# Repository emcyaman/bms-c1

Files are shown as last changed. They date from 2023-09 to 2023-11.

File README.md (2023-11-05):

# Libre Solar BMS C1

 Tested prototype, only minor issues left.

This repository contains the files for ongoing development of the Libre Solar BMS C1.

**Remark:** This BMS was previously named **BMS 16S100 SC**. It was renamed to C1 (with C for compact/centralized) because the maximum current and supported number of cells depend on the parts actually populated on the PCB, so these specs should not be encoded in the PCB name.

The development of this BMS is funded by the [EnAccess foundation](https://enaccess.org).

Schematic: [PDF file](build/bms-c1.pdf)

Bill of Materials: [CSV file](build/bms-c1_bom.csv) or [interactive HTML BOM](https://libre.solar/bms-c1/bms-c1_ibom.html)

Firmware repository: [LibreSolar/bms-firmware](https://github.com/LibreSolar/bms-firmware)

BMS C1

User manual: [libre.solar/bms-c1/manual/](https://libre.solar/bms-c1/manual/)

Mechanical CAD file: [bms-c1.FCStd](housing/bms-c1.FCStd)

Mechanical BOM: [bms-c1_bom_mechanical.csv](housing/bms-c1_bom_mechanical.csv)

Heat sink drawings: [10003_BackPlateAsm.pdf](housing/10003_BackPlateAsm.pdf)

Test report: [testing/v0.3](testing/v0.3/README.md)

## Features

- 3 to 16 Li-ion cells in series
- Continuous current: 70-100A (depending on used MOSFETs and heat sink)
- Cell types: LiFePO4, Li-ion NMC and others (customizable)
- Measurements
  - Cell voltages
  - Pack voltage
  - Pack current
  - Pack (2x), MOSFET and shunt temperatures
- Based on Texas Instruments bq76952
- Integrated high-side MOSFET switch and current sensor
- Espressif ESP32-C3 microcontroller
- Communication interfaces:
  - CAN
  - RS-485 (connector shared with CAN)
  - USB (CDC-ACM and JTAG)
  - USART
  - I2C
  - Bluetooth Low Energy
  - WiFi
- Hardware features
  - 4-layer PCB
  - M5 screw terminals
  - Heat sink at back side
- Applications
  - Off-grid storage
  - Light-electric vehicles (LEV)

## Firmware

The firmware is developed in a separate repository [LibreSolar/bms-firmware](https://github.com/LibreSolar/bms-firmware).

## License

The hardware is licensed under the [CERN Open Hardware Licence Version 2 - Weakly Reciprocal](LICENCE).

Documentation is licensed under the [Creative Commons Attribution-ShareAlike 4.0 International (CC BY-SA 4.0) License](https://creativecommons.org/licenses/by-sa/4.0/).

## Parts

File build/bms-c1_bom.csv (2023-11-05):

Component | References | Value | Footprint | Description | Quantity Per PCB | Manufacturer | PartNumber | Remarks
1 | C27 C29 C32 C33 C35 C38 | 100pF | C_0603_1608 | Unpolarized capacitor | 6 | any |  | 100V, C0G/NP0
2 | C19 C21 C24 C28 C31 C34 C36 C37 C40 C48 C49 C50 C51 C52 | 100nF | C_0603_1608 | Unpolarized capacitor | 14 | any |  | X7R, 100V
3 | C1 C2 C3 C4 C5 C6 C7 C8 C9 C10 C11 C12 C13 C14 C15 C16 C26 | 220nF | C_0603_1608 | Unpolarized capacitor | 17 | any
4 | C25 | 1µF | C_1206_3216 | Unpolarized capacitor | 1 | any |  | 100V, X7R
5 | C30 C47 | 1µF | C_0603_1608 | Unpolarized capacitor | 2 | any |  | 25V, X5R
6 | C46 | 10µF | C_0805_2012 | Unpolarized capacitor | 1 | Murata | GRM21BR61E106KA73L | 25V, X5R
7 | C20 | 2.2µF | C_0603_1608 | Unpolarized capacitor | 1 | any |  | X7R, 10V
8 | C22 C23 | 2.2µF | C_1210_3225 | Unpolarized capacitor | 2 | any |  | 100V, X7R
9 | C17 C18 | 47µF | C_1210_3225 | Unpolarized capacitor | 2 | Samsung | CL32B476MPJNNNE | 10V, X5R
10 | D14 D17 D21 D24 | 16V | D_SOD-123 | Zener diode | 4 | Diodes Incorporated | MMSZ5246B-7-F | Alternative: Vishay MMSZ5246B-HE3-08
11 | D11 | 3.6V | D_SOD-123 | Zener diode | 1 | onsemi | MMSZ4685T1G
12 | D19 | 5.1V | D_SOD-323 | Zener diode | 1 | Diodes Incorporated | BZT52C5V1S-7-F | Vishay BZX384C5V1
13 | D23 | 75V | D_SOD-123 | Zener diode | 1 | Diodes Incorporated | MMSZ5267BT1G
14 | D2 D5 D10 D15 D16 D20 | BAT46W | D_SOD-123 | Schottky diode | 6 | Diodes Incorporated | BAT46W-7-F | Alternative: MCC BAT46WHE3-TP
15 | D3 D4 | ESD5B5.0ST1G | D_SOD-523 | ESD protection diode, 5.0Vrwm, SOD-923 | 2 | onsemi | ESD5B5.0ST1G
16 | D22 | MURS360 | D_SMC | Diode | 1 | Diodes Incorporated | MURS360 | Alternative: Other MURS360
17 | D8 | PESD2CANFD | SOT-23 | Dual Line CAN Bus Protector, 24Vrwm | 1 | Nexperia | PESD2CANFD24V-TR | Alternative: onsemi ESDONCAN1LT
18 | D1 | PMEG10010ELRX | D_SOD-123F | Schottky diode | 1 | Nexperia | PMEG10010ELRX | Alternative: Nexperia PMEG10030ELPX
19 | D13 | PMEG10010ELRX | D_SOD-123F | Schottky diode | 1 | Nexperia | PMEG10010ELRX | Alternative: Nexperia PMEG10030ELPX
20 | D12 | SMCJ70A | D_SMC | Zener diode | 1 | Bourns | SMCJ70A | Alternative: Diodes Inc. SMCJ70A-13-F
21 | D9 | VSS8D3M10-M3/I | D_SOD-128 | Schottky diode | 1 | Vishay | VSS8D3M10-M3/I | Alternative: Nexperia PMEG10030ELPX
22 | J5 | B2B-PH-SM4 | JST_PH_B2B-PH-SM4-TB_1x02-1MP_P2.00mm_Vertical | Generic connectable mounting pin connector, single row, 01x02, script generated (kicad-library-utils/schlib/autogen/connector/) | 1 | JST | B2B-PH-SM4-TB(LF)(SN) | Alternative: Würth 620302124022
23 | J4 | B3B-PH-SM4 | JST_PH_B3B-PH-SM4-TB_1x03-1MP_P2.00mm_Vertical | Generic connectable mounting pin connector, single row, 01x03, script generated (kicad-library-utils/schlib/autogen/connector/) | 1 | JST | B3B-PH-SM4-TB(LF)(SN) | Alternative: Würth 620303124022
24 | J2 J6 | B4B-PH-SM4 | JST_PH_B4B-PH-SM4-TB_1x04-1MP_P2.00mm_Vertical | Generic connectable mounting pin connector, single row, 01x04, script generated (kicad-library-utils/schlib/autogen/connector/) | 2 | JST | B4B-PH-SM4-TB(LF)(SN) | Alternative: Würth 620304124022
25 | J1 | MicroFit 2x12 | Molex_Micro-Fit_3.0_43045-2410_2x12-1MP_P3.00mm_Horizontal | Generic connectable mounting pin connector, double row, 02x12, top/bottom pin numbering scheme (row 1: 1...pins_per_row, row2: pins_per_row+1 ... num_pins), script generated (kicad-library-utils/schlib/autogen/connector/) | 1 | Würth | 662024231722 | Mating connector: 662024113322
26 | J3 | USB_C_Receptacle_USB2.0 | USB_C_Receptacle_GCT_USB4105-xx-A_16P_TopMnt_Horizontal | USB 2.0-only Type-C Receptacle connector | 1 | GCT | USB4105-GF-A
27 | L2 | 22µH | Bourns_SRN8040TA | Inductor, small symbol | 1 | Tayo Yuden | NR8040T100M | Alternative: Bourns SRN8040TA-100M
28 | LED2 | LED green | LED_0603_1608Metric | Light emitting diode | 1 | any |  | green
29 | LED1 | LED red | LED_0603_1608Metric | Light emitting diode | 1 | any |  | red
30 | P1 P2 P3 P4 | CONN_01X01 | Wuerth_WP-SMBU_7466005R | Generic connector, single row, 01x01, script generated (kicad-library-utils/schlib/autogen/connector/) | 4 | Würth | 7466005R | Alternative: Erni 225858
31 | P5 | CONN_01X01 | SolderWirePad_1x01_SMD_5x10mm | Generic connector, single row, 01x01, script generated (kicad-library-utils/schlib/autogen/connector/) | 1
32 | Q11 | BSS123N | SOT-23 | N-MOSFET transistor, gate/source/drain | 1 | any | BSS123N
33 | Q10 | BSS84 | SOT-23 | P-MOSFET transistor, gate/source/drain | 1 | Nexperia | BSS84AK,215 | at least -20V
34 | Q1 | DMN10H220LE | SOT-223 | N-MOSFET transistor, gate/drain/source, drain connected to mounting plane | 1 | Diodes Inc. | DMN10H220LE | 100V, >2A, Alternative: IRFM120ATF
35 | Q2 Q3 Q4 Q5 Q6 Q7 Q8 Q9 | IPT015N10N5 | Infineon_PG-HSOF-8-1_ThermalVias | N-MOSFET transistor, gate/source/drain | 8 | Infineon | IPT015N10N5 | Alternative with 2mOhm: IPT020N10N3
36 | Q12 | ZXMP10A17GTA | SOT-223-3_TabPin2 | P-MOSFET transistor, gate/drain/source | 1 | Diodes Incorporated | ZXMP10A17GTA | Alternative: IRFL9110TRPBF
37 | R21 R37 | 0R | R_0603_1608 | Resistor | 2 | any
38 | R25 | 10 | R_1206_3216 | Resistor | 1 | any
39 | R1 R2 R3 R4 R5 R6 R7 R8 R9 R10 R11 R12 R13 R14 R15 R16 R17 | 20 | R_2010_5025 | Resistor | 17 | Yageo | RC2010JK-0720RL
40 | R63 | 40 | Bourns_PWR163 | Trim-potentiometer | 1 | Bourns | PWR163S-25-40R0FE
41 | R40 R41 R42 R43 R47 R48 R49 R50 R57 | 47 | R_0603_1608 | Resistor | 9 | any
42 | R34 | 52.3 | R_0603_1608 | Resistor | 1 | any |  | 1%
43 | R56 R64 | 62R | R_0603_1608 | Resistor | 2 | any
44 | R18 | 100 | R_1206_3216 | Resistor | 1 | any
45 | R19 R20 R38 R44 | 100 | R_0603_1608 | Resistor | 4 | any
46 | R45 | 300µ | R_Shunt_5931_Kelvin | Shunt resistor | 1 | Vishay | WSLP5931L3000FEA | Alternative: Bourns CSS2H-5930R-L300F
47 | R58 | 470 | R_0603_1608 | Resistor | 1 | any
48 | R22 R23 R46 | 1k | R_0603_1608 | Resistor | 3 | any
49 | R32 R33 | 2.2k | R_0603_1608 | Resistor | 2 | any
50 | R27 R35 R53 R54 | 5.1k | R_0603_1608 | Resistor | 4 | any
51 | R29 R30 R60 R68 | 10k | R_0603_1608 | Resistor | 4 | any
52 | R31 | 35.7k | R_0603_1608 | Resistor | 1 | any |  | 1%
53 | R51 R61 | 68k | R_0603_1608 | Resistor | 2 | any
54 | R28 R65 | 82k | R_0603_1608 | Resistor | 2 | any |  | 1%
55 | R24 R26 R62 | 1M | R_0603_1608 | Resistor | 3 | any
56 | R39 R52 R59 | 10M | R_0603_1608 | Resistor | 3 | any
57 | RT1 RT2 | 10k | R_0603_1608 | Thermistor with Negative Temperature Coefficient (NTC) | 2 | TDK | NTCG163JF103FT1S
58 | S1 S2 | SW_PUSH | SW_SPST_TL3305A | Button | 2 | E-Switch | TL3305AF160QG
59 | U4 | BQ76952 | TQFP-48_7x7mm_P0.5mm | Lithium battery monitor, 3-16 cells, integrated balancing, I2C interface, TQFP-48 | 1 | Texas Instruments | BQ76952PFBR
60 | U5 | ESP32-C3-MINI-1 | ESP32-C3-MINI-1 | ESP32-C3-MINI-1 is a general-purpose Wi-Fi and Bluetooth LE module. This module features a rich set of peripherals and a small size, which makes it an ideal choice for smart home, industrial automation, health care, consumer electronics, etc | 1 | Espressif Systems | ESP32-C3-MINI-1-N4
61 | U3 | LMR38020 | SOIC-8-1EP_3.9x4.9mm_P1.27mm_EP2.4x3.1mm_ThermalVias | SIMPLE SWITCHER® 60-V, 3-A Step-Down Converter With 40-µA IQ | 1 | Texas Instruments | LMR38020SDDAR
62 | U1 | SN65HVD230 | SOIC-8_3.9x4.9mm_P1.27mm | CAN Bus Transceivers, 3.3V, 1Mbps, Low-Power capabilities, SOIC-8 | 1 | Texas Instruments | SN65HVD230D | Alternative: SN65HVD230QDR
63 | U2 | SN65HVD75 | SOIC-8_3.9x4.9mm_P1.27mm | 3.3V, RS-485 Transceiver, SOIC-8 | 1 | Texas Instruments | SN65HVD75DR | Alternative: ISL3178E

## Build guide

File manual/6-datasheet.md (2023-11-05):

# Datasheet

--------------------------------------------------------------------------------------------
Feature                         Value                   Comment
------------------------------  ----------------------- ------------------------------------
**Battery**

Nominal voltage range           12 V to 48 V

Maximum voltage                 70 V

Maximum current                 70 A - 100 A            Depending on ambient conditions and
                                                        heat sink

Self consumption                < 20 mA                 Exact value t.b.d.

Shutdown current                < 1 mA                  Exact value t.b.d.

Cell types                      LFP, NMC and others     Customizable through firmware

**Interfaces**

CAN 2.0

RS-485 (connector shared with CAN)

USB CDC-ACM

UART serial

I2C

Bluetooth

**Protection**

Over-/undervoltage

Overcurrent / Short circuit

Over-/undertemperature

**Environmental conditions**

Operating ambient temperature   -10 °C to +50 °C

Storage temperature             -20 °C to +60 °C

Humidity                        <95%, non-condensing

**Mechanical design**

Screw terminals                 M5, torque: 2.2 Nm

Weight                          t.b.d.

Dimensions                      70 mm x 135 mm
------------------------------  ----------------------- ------------------------------------

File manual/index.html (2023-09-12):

# Libre Solar BMS C1

# 1 Introduction

The Libre Solar BMS C1 is a flexible Open Source Battery Management System (BMS) suitable for various applications.

This manual describes the usage and most important functions of the BMS. Please visit learn.libre.solar for general information about battery management systems, charge controllers and other devices for DC energy systems.

Read this manual carefully and make sure you understand everything before starting with installation of the BMS.

Same as the hardware and firmware of the BMS, also this manual is Open Source. If you find any errors or have suggestions for improvement, please contribute to the repository on GitHub (https://github.com/LibreSolar/bms-c1/).

## 1.1 Project background

The main target of the project behind this BMS is to provide a solid technical basis for custom developments of organizations working in the energy access sector.

The project is funded by the EnAccess Foundation (https://enaccess.org/).



The development is driven by the Libre Solar and EnAccess Communities. Visit the following websites for most recent updates:

- EnAccess Community: community.enaccess.org
- Libre Solar Community: talk.libre.solar

Hardware and firmware source files are published on GitHub:

- Hardware Repository: github.com/LibreSolar/bms-c1
- Firmware Repository: github.com/LibreSolar/bms-firmware

## 1.2 Disclaimer

This user manual has been written and checked with care and to the best of our knowledge.

Libre Solar assumes no liability for the accuracy, completeness or quality of the information provided. Liability claims against the team for material, physical or immaterial damages caused by the use or non-use of the information provided or by the use of incorrect and/or incomplete information are excluded.

All information and instructions are non-binding. Libre Solar reserves the right to change, supplement or delete parts of the pages or the entire document without prior notice.

## 1.3 License

This user manual document is licensed under the Creative Commons Attribution-ShareAlike 4.0 International (CC BY-SA 4.0) License.



The full license text is available at https://creativecommons.org/licenses/by-sa/4.0/.

# 2 Safety Instructions

- The BMS shall only be used for the intended application.
- The maximum voltage and current of the connected batteries or loads must not exceed the limits of the BMS.
- Ensure that the BMS is configured correctly for the used battery type.
- Install the device considering general best practices for electrical and mechanical installations in accordance to laws in your country.
- An additional fuse must be installed as close to the battery positive terminal as possible.
- As sparks can occur during connection of the battery wires, don’t install the BMS close to any flammable materials.
- The wire cross-section has to be large enough to handle at least the maximum specified current of the BMS.
- Use insulated tools only.
- Fix the wires outside the BMS to provide a strain relief and reduce forces on the terminals.
- Mount the device on a solid, non-inflammable material only. Depending on the ambient conditions and the average current, a heat sink may be required.

# 3 Features

## 3.1 System overview

The BMS is the heart of every Li-ion battery. It is needed to equalize series connected cells and protect the battery from current, voltages and temperatures outside the allowed operating range.

Below figure shows a complete battery system with the integrated BMS.

Overview of the BMS integrated into a Li-ion battery pack.

Overview of the BMS integrated into a Li-ion battery pack.

This BMS has the following high-level features:

- Flexible and fully Open Source design
- Suitable for 12V, 24V or 48V systems (up to 16 LFP cells in series)
- Continuous currents of up to 100A

With above specifications it is suitable for the following applications:

- Poductive use appliances like milling machines
- Energy storage for AC mini-grid applications with up to 4 kVA inverters
- Second-life batteries built e.g. from recycled EV batteries
- Generic off-grid energy storage e.g. in caravans

## 3.2 Hardware

BMS Overview

BMS Overview

### 3.2.1 Board design

All electronics components (power and control) are integrated into a single PCB in order to reduce cost and size.

The board contains the following main subsystems:

- Power part (top left)
  - High current terminals
  - MOSFETs (4 in parallel, 2 in series for bi-directional switching)
  - Current measurement shunt
- Control part (bottom right)
  - Microcontroller: ESP32-C3
  - BMS ASIC: Texas Instruments BQ76952
  - Internal power supply
  - Communication interfaces (CAN, UART, I2C, USB, Bluetooth)

### 3.2.2 MCU: ESP32-C3

The Espressif ESP32-C3 (https://www.espressif.com/en/products/socs/esp32-c3) is a single-core microcontroller featuring Wi-Fi, Bluetooth 5 (LE) and CAN (called TWAI by Espressif). It is based on the open-source RISC-V architecture.

### 3.2.3 BMS IC: BQ76952

The Texas Instruments BQ76952 (https://www.ti.com/product/BQ76952) was selected as the BMS IC as it offers a good compromise between accuracy, features and cost.

Features according to Datasheet:

- Battery monitoring capability for 3-series to 16-series cells
- Integrated charge pump for high-side NFET protection with optional autonomous recovery
- Extensive protection suite including voltage, temperature, current, and internal diagnostics
- Two independent ADCs
- Support for simultaneous current and voltage sampling
- High-accuracy coulomb counter with input offset error < 1 uV (typical)
- High accuracy cell voltage measurement < 10 mV (typical)
- Wide-range current applications (±200-mV measurement range across sense resistor)
- Integrated secondary chemical fuse drive protection
- Autonomous or host-controlled cell balancing
- Multiple power modes (typical battery pack operating range conditions)
- NORMAL mode: 286 uA
- Multiple SLEEP mode options: 24 uA to 41 uA
- Multiple DEEPSLEEP mode options: 9 uA to 10 uA
- SHUTDOWN mode: 1 uA
- High-voltage tolerance of 85 V on cell connect and select additional pins
- Tolerant of random cell attach sequence on production line
- Support for temperature sensing using internal sensor and up to nine external thermistors
- Integrated one-time-programmable (OTP) memory programmable by customers on production line
- Communication options include 400-kHz I2C, SPI, and HDQ one-wire interface
- Dual-programmable LDOs for external system usage
- 48-pin TQFP package (PFB)

### 3.2.4 Balancing

The BMS features passive balancing with up to 100 mA.

### 3.2.5 Protective switches

The positive battery terminal can be disconnected by the BMS for safety reasons or upon demand of the user via a communicatoin interface.

The disconnect switches are N-channel MOSFETs in a back-to-back configuration to be able to interrupt current in both directions (see also BQ76952 datasheet). In order to allow the high currents, 4 MOSFETs are connected in parallel.

The bottom side of the PCB can be attached to a heat sink to dissipate the heat at high continuous currents.

The cell connector has a pin to trigger a fuse at the pack positive terminal as a secondary protection if the MOSFETs fail short.

### 3.2.6 Current measurement

The current is measured using a shunt, located in the negative voltage path of the battery pack. The shunt voltage is amplified by the BQ76952 ASIC and read by the MCU.

Time-critical safety features like overcurrent and short circuit protection are implemented directly in the ASIC and can be calibrated via firmware.

### 3.2.7 Cell and thermistor connectors

The cells and thermistors are connected to the BMS using Molex Micro-Fit (https://www.molex.com/molex/products/family/microfit_30) or Würth WR-MPC3 (https://www.we-online.com/katalog/en/em/connectors/wire-to-board/wr_mpc3) series connectors.

Both series are pin-compatible and there are even more compatible connectors in the market for this popular series. The connectors can handle up to 5A, which is sufficient even for active balancing.

### 3.2.8 Power connectors

The BMS is designed for up to 100A continuous current, depending on ambient temperatures, heat sink and actually fitted MOSFETs.

Würth high-power solder terminals with M5 threads are used for wire-to-board connections.

## 3.3 Communication interfaces

One major advantage of an Open Source design is its extensibility and adaptation to specific requirements.

In order to provide the hardware interfaces required to add custom extensions, two options are offered. Communication between multiple BMSs or other devices like charge controllers can be achieved via CAN bus, while the addional interfaces like I2C and UART can be used for extension of the board with internal features like displays.

The MCU features built-in WiFi and Bluetooth communication.

The serial and Bluetooth communication interfaces use the ThingSet protocol (https://thingset.io/) by default, which allows to read measurement values from the BMS as well as store custom configuration.

## 3.4 Firmware

The firmware is based on Zephyr RTOS (https://www.zephyrproject.org/) and thus allows for easy integration of additional communication features. The latest Zephyr long-term support release is in the process of being certified for functional safety according to IEC 61508.

Amongst all features inherited from underlying Zephyr, the BMS firmware has the additional BMS-specific features:

- Monitoring and configuration using the ThingSet (https://thingset.io/) protocol (mapping to MQTT, CoAP and HTTP possible)
  - Serial interface
  - CAN bus
  - I2C
  - Bluetooth
  - WiFi
- SOC estimation based on coulomb counting
- Configuration options
  - Pack layout
    - Cell chemistry (LiFePO4, NMC, NCA)
    - Nominal capacity
    - Number of cells
    - Thermistor type
    - Shunt resistor
    - Custom open circuit voltage (OCV) look-up table
  - Protection
    - Discharge short circuit limit (A)
    - Discharge short circuit delay (us)
    - Discharge over-current limit (A)
    - Discharge over-current delay (ms)
    - Charge over-current limit (A)
    - Charge over-current delay (ms)
    - Cell target charge voltage (V)
    - Cell discharge voltage limit (V)
    - Cell over-voltage limit (V)
    - Cell over-voltage error reset threshold (V)
    - Cell over-voltage delay (ms)
    - Cell under-voltage limit (V)
    - Cell under-voltage error reset threshold (V)
    - Cell under-voltage delay (ms)
    - Discharge over-temperature (DOT) limit (°C)
    - Discharge under-temperature (DUT) limit (°C)
    - Charge over-temperature (COT) limit (°C)
    - Charge under-temperature (CUT) limit (°C)
    - Temperature limit hysteresis (°C)
  - Balancing
    - Enable automatic balancing.
    - Balancing cell voltage target difference (V)
    - Minimum cell voltage to start balancing (V)
    - Current threshold to be considered idle (A)
    - Minimum idle duration before balancing (s)

# 4 Installation

Attention: The maximum operating voltage of the BMS is 60V. The 16s configuration is only feasible for LFP cells. For NMC cells, a maximum number of 14 cells may be used.

## 4.1 Mechanical Design

The board dimensions are 70x135 mm² so that it can be easily integrated into existing housings with typical 18650 or 2170 cells.

BMS mounted on a heat sink

BMS mounted on a heat sink

Depending on the current requirements and ambient temperatures, a heat sink may be required. For good thermal contact, a thermal interface material (e.g. Henkel/Bergquist GAP PAD A2000) is required, as shown in above picture.

## 4.2 Connections

Below picture shows the connections of the cells, the 10k thermistors (NTC1 and NTC2) and the high power cables.

BMS connections

BMS connections

The BMS is powered through the BAT+ terminal. If only the cell connector is mounted, the power is provided through the additional BAT+ wire in the cell connector, which has to be connected to the last cell’s positive terminal.

The BMS cannot be powered through the USB port only.

### 4.2.1 Power connections

The high power terminals have an M5 thread and allow to fit wires of up to 35 mm² cross-section.

The nuts and washers should be made from stainless steel to avoid corrosion with copper cable lugs.

The wires must be properly fixed in the housing to reduce stress on the soldered terminals on the PCB.

The fixing torque for the nuts is 2.2 Nm. Use of a torque wrench is highly recommended.

### 4.2.2 Signal connections

The MPC3 / Microfit connector must be equipped with properly crimped wires connected to the cells and the thermistors. Würth sells pre-crimped wires (https://www.we-online.com/de/components/products/em/connectors/wire-to-board/wr_mpc3/wr_mpc3_pre_crimped_wire) so that no crimping tool is needed (the low-force type is recommended). These wires can be cut in half and connected to an own wiring harness.

If less than 16 cells are used, the unused cell connections have to be short-circuited (either on the PCB using the pads left of the balancing resistors or in the wiring harness). See also the BQ76952 documentation (https://www.ti.com/product/BQ76952) for further details.

At least NTC1 has to be connected and show a valid temperature range for the BMS to allow charging/discharging.

### 4.2.3 Connection order

1. Connect the fully wired cell connector. (Note the two separate connections to the first cell’s negative terminal)
2. Connect the BAT- terminal.
3. Connect the BAT+ terminal (with a fuse in line, as shown).
4. Connect load or charger.

## 4.3 Communication ports

The CAN, UART and I2C communication ports use JST PH connectors. The pinout is marked on the PCB.

The I2C is shared with the BQ76952. It must be ensured that this communication is not disturbed by another component on the I2C bus.

# 5 Operation

## 5.1 Firmware flashing

If no firmware is flashed on the board, make sure the board is powered through the cell connector. The power wires BAT+ and BAT- are optional.

The firmware is flashed through the USB port. Follow the instructions in the Firmware repository (https://github.com/LibreSolar/bms-firmware).

## 5.2 Start-up

In order to wake up the BMS chip, short-press the ON/OFF button S1 (top-right corner).

If the button is long-pressed for at least 3 seconds, the BMS will go into low-power shutdown mode.

A custom push-button as part of the battery housing can be connected to the connector J5 next to the button.

## 5.3 LED indications

The BMS is equipped with two status LEDs with below indications:

Red LED:

Status | Meaning
off | Discharging finished and battery is empty
on | Discharging allowed (current below idle threshold)
blinking slowly | Discharging active (current above idle threshold)
flashing quickly | Discharging error (UV/OT/UT/OC/SC)

Green LED:

Status | Meaning
off | Charging finished and battery is full
on | Charging allowed (current below idle threshold)
blinking slowly | Charging active (current above idle threshold)
flashing quickly | Charging error (OV/OT/UT/OC)

## 5.4 Communication Setup

Device information, configuration values and measurements can be explored using the ThingSet protocol (https://thingset.io/). This protocol is used for the serial interface as well as the Bluetooth communication.

For details regarding the protocol consider the specification linked above. The basic setup is explained below.

### 5.4.1 USB Serial

The USB virtual COM port exposes log data and the Zephyr shell. Among other commands, the shell can also be used for communication using the ThingSet protocool.

A terminal program like picocom is recommended:

picocom /dev/ttyACM0

The shell command for the ThingSet protocol is thingset. Either prefix it for every command or select thingset to switch into ThingSet mode.

select thingset
?Meas
:85 {"rPackVoltage_V":13.71,"rStackVoltage_V":13.91,"rPackCurrent_A":0.05,"rBatTemp_degC":29.4,"rICTemp_degC":34.2,"rMOSFETTemp_degC":31.8,"rSOC_pct":100.0,"rErrorFlags":0,"rBmsState":3,"rCellVoltages_V":[3.495,3.497,3.486,3.495,0.000,0.000,0.000,0.000,0.000,0.000,0.000,0.000,0.000,0.000,0.000,0.000],"rCellAvgVoltage_V":3.493,"rCellMinVoltage_V":3.486,"rCellMaxVoltage_V":3.497,"rBalancingStatus":0}

When using the shell, the quotation marks in JSON data have to be escaped. See below for an example:

=Conf {\"sCellOvervoltage_V\": 3.8}
:84

### 5.4.2 UART Serial

The serial interface uses a baud-rate of 115200 bps. Depending on the operating system, you can use different tools to communicate with the serial interface manually.

For Linux CuteCom (https://sourceforge.net/projects/cutecom/) is recommended, as it stores a history of previous commands.

The Serial2Websocket Python script (https://github.com/ThingSet/thingset-serial2websocket) can be used as a basis for own scripts to use the monitoring data.

### 5.4.3 BLE

The generic ThingSet app (https://github.com/ThingSet/thingset-app) can be used to connect to the BMS via Bluetooth LE.

For own developments see the BLE transport layer specification on the ThingSet website and consider the implementation of the device side in the ThingSet Zephyr SDK (https://github.com/ThingSet/thingset-zephyr-sdk).

## 5.5 Configuration

The ThingSet protocol itself allows to discover available data items for configuration, so this manual will only use some examples for demonstration purposes.

### 5.5.1 Read measurements and battery status

Use the following command to get the current state of the battery, including all current, temperature and voltage measurements:

?Meas

### 5.5.2 Configure battery type

The configuration for a particular cell type and battery size can be preset with suitable default values using the two executable data items xPresetNMC for NMC cells and xPresetLFP for LFP cells. The functions expect a parameter defining the nominal capacity of the battery in Ah.

For an LFP battery with 45 Ah, send the following command to the BMS:

!Conf/xPresetLFP [45]

The expected response if the parameters were successfully set:

:84 0

### 5.5.3 Adjust thresholds

The current configuration can be determined with the following command:

?Conf

Individual parameters can be adjusted with a command as shown below (using the overvoltage threshold as an example):

=Conf {"sCellOvervoltage_V": 3.8}

# 6 Datasheet

Feature | Value | Comment
Battery
Nominal voltage range | 12 V to 48 V
Maximum voltage | 60 V | (only 14s for NMC allowed)
Maximum current | 70 A - 100 A | Depending on ambient conditions and heat sink
Self consumption | < 20 mA | Exact value t.b.d.
Shutdown current | < 1 mA | Exact value t.b.d.
Cell types | LFP, NMC and others | Customizable through firmware
Interfaces
CAN 2.0
USB CDC-ACM
UART serial
I2C
Bluetooth
Protection
Over-/undervoltage
Overcurrent / Short circuit
Over-/undertemperature
Environmental conditions
Operating ambient temperature | -10 °C to +50 °C
Storage temperature | -20 °C to +60 °C
Humidity | <95%, non-condensing
Mechanical design
Screw terminals | M5, torque: 2.2 Nm
Weight | t.b.d.
Dimensions | 70 mm x 135 mm

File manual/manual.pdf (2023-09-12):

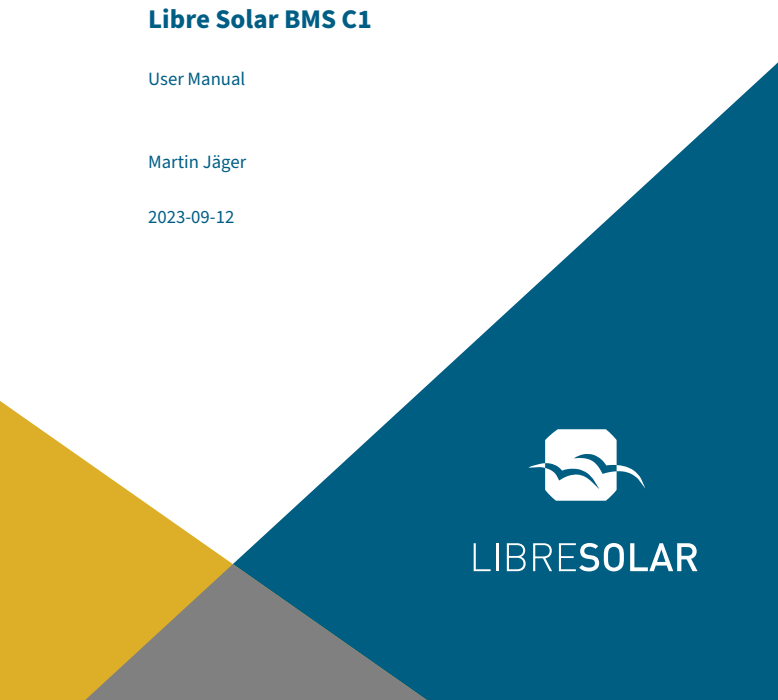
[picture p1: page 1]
User Manual; Martin Jäger

Libre Solar BMS C1

Libre Solar BMS C1 | User Manual

## Contents

1 Introduction | 4
2 Safety Instructions | 6
3 Features | 7
4 Installation | 13
5 Operation | 16
Libre Solar | 2

Libre Solar BMS C1 | User Manual
6 Datasheet | 20
Libre Solar | 3

Libre Solar BMS C1 | User Manual

## 1 Introduction

The Libre Solar BMS C1 is a flexible Open Source Battery Management System (BMS) suitable for various applications.

This manual describes the usage and most important functions of the BMS. Please visit learn.libre.solar for general information about battery management systems, charge controllers and other devices for

DC energy systems.

Read this manual carefully and make sure you understand everything before starting with installation of the BMS.

Same as the hardware and firmware of the BMS, also this manual is Open Source. If you find any errors or have suggestions for improvement, please contribute to the repository on GitHub. (https://github.com/LibreSolar/bms-c1/)

### 1.1 Project background

The main target of the project behind this BMS is to provide a solid technical basis for custom developments of organizations working in the energy access sector.

The project is funded by the EnAccess Foundation. (https://enaccess.org/)

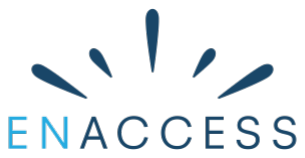
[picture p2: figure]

The development is driven by the Libre Solar and EnAccess Communities. Visit the following websites for most recent updates:

- EnAccess Community: community.enaccess.org
- Libre Solar Community: talk.libre.solar

Hardware and firmware source files are published on GitHub:

- Hardware Repository: github.com/LibreSolar/bms-c1
- Firmware Repository: github.com/LibreSolar/bms-firmware

### 1.2 Disclaimer

This user manual has been written and checked with care and to the best of our knowledge.

Libre Solar | 4

Libre Solar BMS C1 | User Manual

Libre Solar assumes no liability for the accuracy, completeness or quality of the information provided. Liability claims against the team for material, physical or immaterial damages caused by the use or non-use of the information provided or by the use of incorrect and/or incomplete information are excluded.

All information and instructions are non-binding. Libre Solar reserves the right to change, supplement or delete parts of the pages or the entire document without prior notice.

### 1.3 License

This user manual document is licensed under the Creative Commons Attribution-ShareAlike 4.0 International (CC BY-SA 4.0) License.

The full license text is available at https://creativecommons.org/licenses/by-sa/4.0/.

Libre Solar | 5

Libre Solar BMS C1 | User Manual

## 2 Safety Instructions

- The BMS shall only be used for the intended application.
- The maximum voltage and current of the connected batteries or loads must not exceed the limits of the BMS.
- Ensure that the BMS is configured correctly for the used battery type.
- Install the device considering general best practices for electrical and mechanical installations in accordance to laws in your country.
- An additional fuse must be installed as close to the battery positive terminal as possible.
- As sparks can occur during connection of the battery wires, don’t install the BMS close to any flammable materials.
- The wire cross-section has to be large enough to handle at least the maximum specified current of the BMS.
- Use insulated tools only.
- Fix the wires outside the BMS to provide a strain relief and reduce forces on the terminals.
- Mount the device on a solid, non-inflammable material only. Depending on the ambient conditions and the average current, a heat sink may be required.
Libre Solar | 6

Libre Solar BMS C1 | User Manual

## 3 Features

### 3.1 System overview

The BMS is the heart of every Li-ion battery. It is needed to equalize series connected cells and protect the battery from current, voltages and temperatures outside the allowed operating range.

Below figure shows a complete battery system with the integrated BMS.

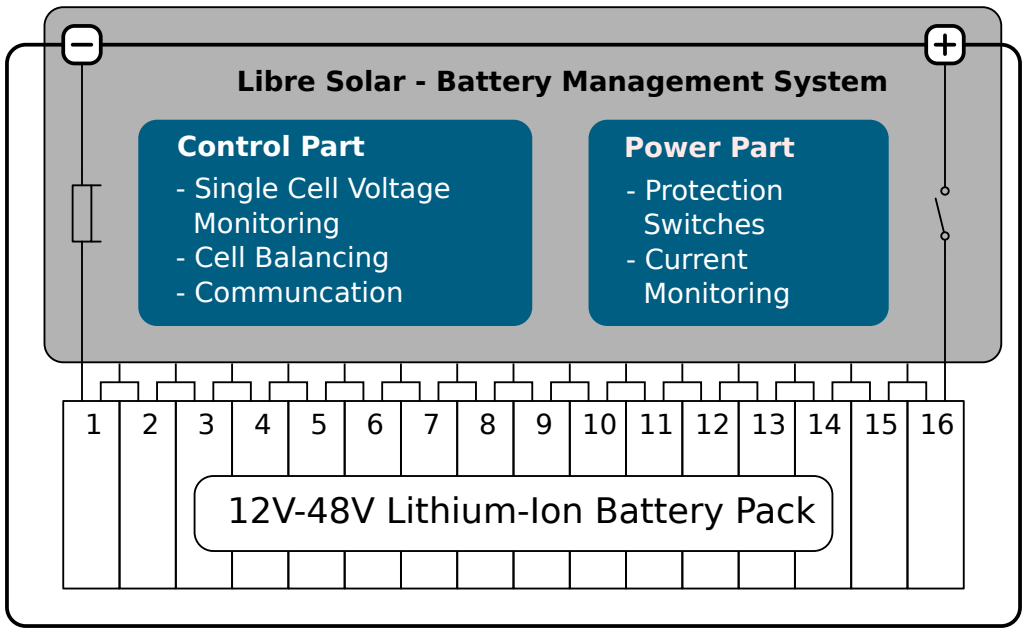
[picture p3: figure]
Control Part; Power Part; Libre Solar - Battery Management System; - Protection Switches - Current Monitoring; - Single Cell Voltage Monitoring - Cell Balancing - Communcation; 12V-48V Lithium-Ion Battery Pack

Figure 1: Overview of the BMS integrated into a Li-ion battery pack.

This BMS has the following high-level features:

- Flexible and fully Open Source design
- Suitable for 12V, 24V or 48V systems (up to 16 LFP cells in series)
- Continuous currents of up to 100A

With above specifications it is suitable for the following applications:

- Poductive use appliances like milling machines
- Energy storage for AC mini-grid applications with up to 4 kVA inverters
- Second-life batteries built e.g. from recycled EV batteries
- Generic off-grid energy storage e.g. in caravans
Libre Solar | 7

Libre Solar BMS C1 | User Manual

### 3.2 Hardware

## ON/OFF switch and connector

## Shunt resistor

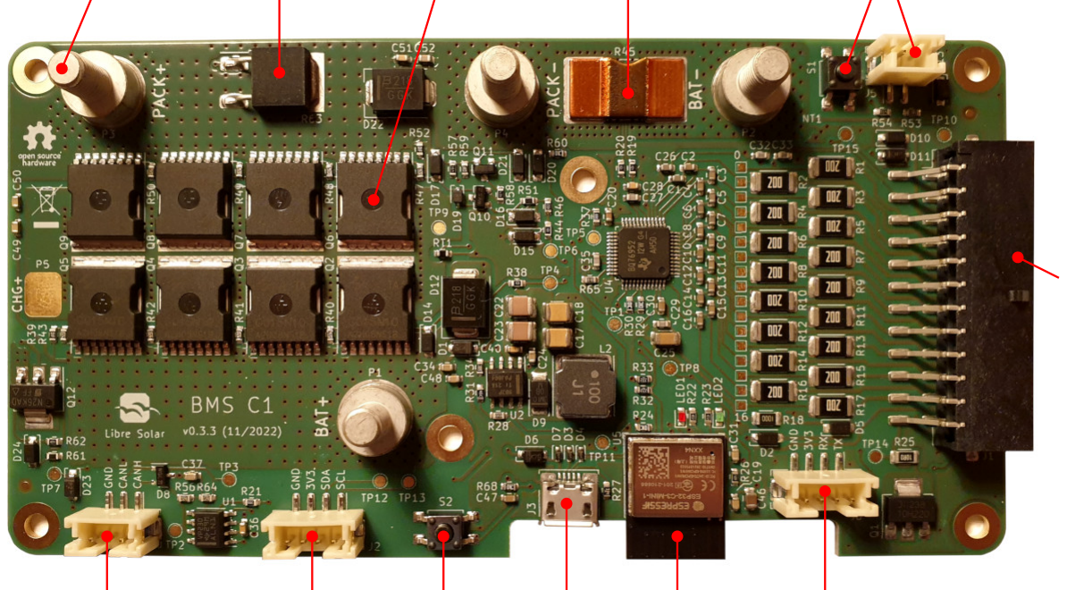
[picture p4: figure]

CAN | I2C | USART

## Cells and Thermistors

USBReset | BLE

## Power Connectors

## Precharge resistor MOSFETs

Figure 2: BMS Overview

### 3.2.1 Board design

All electronics components (power and control) are integrated into a single PCB in order to reduce cost and size.

The board contains the following main subsystems:

- Power part (top left)

– High current terminals
– MOSFETs (4 in parallel, 2 in series for bi-directional switching) – Current measurement shunt
- Control part (bottom right)

– Microcontroller: ESP32-C3
– BMS ASIC: Texas Instruments BQ76952
– Internal power supply
– Communication interfaces (CAN, UART, I2C, USB, Bluetooth)
Libre Solar | 8

Libre Solar BMS C1 | User Manual

### 3.2.2 MCU: ESP32-C3

The Espressif ESP32-C3 (https://www.espressif.com/en/products/socs/esp32-c3) is a single-core microcontroller featuring Wi-Fi, Bluetooth 5 (LE) and CAN (called TWAI by Espressif). It is based on the open-source RISC-V architecture.

### 3.2.3 BMS IC: BQ76952

The Texas Instruments BQ76952 (https://www.ti.com/product/BQ76952) was selected as the BMS IC as it offers a good compromise between accuracy, features and cost.

Features according to Datasheet:

- Battery monitoring capability for 3-series to 16-series cells
- Integrated charge pump for high-side NFET protection with optional autonomous recovery
- Extensive protection suite including voltage, temperature, current, and internal diagnostics
- Two independent ADCs
- Support for simultaneous current and voltage sampling
- High-accuracy coulomb counter with input offset error < 1 uV (typical)
- High accuracy cell voltage measurement < 10 mV (typical)
- Wide-range current applications (±200-mV measurement range across sense resistor)
- Integrated secondary chemical fuse drive protection
- Autonomous or host-controlled cell balancing
- Multiple power modes (typical battery pack operating range conditions)
- NORMAL mode: 286 uA
- Multiple SLEEP mode options: 24 uA to 41 uA
- Multiple DEEPSLEEP mode options: 9 uA to 10 uA
- SHUTDOWN mode: 1 uA
- High-voltage tolerance of 85 V on cell connect and select additional pins
- Tolerant of random cell attach sequence on production line
- Support for temperature sensing using internal sensor and up to nine external thermistors
- Integrated one-time-programmable (OTP) memory programmable by customers on production line
- Communication options include 400-kHz I2C, SPI, and HDQ one-wire interface
- Dual-programmable LDOs for external system usage
- 48-pin TQFP package (PFB)

### 3.2.4 Balancing

The BMS features passive balancing with up to 100 mA.

Libre Solar | 9

Libre Solar BMS C1 | User Manual

### 3.2.5 Protective switches

The positive battery terminal can be disconnected by the BMS for safety reasons or upon demand of the user via a communicatoin interface.

The disconnect switches are N-channel MOSFETs in a back-to-back configuration to be able to interrupt current in both directions (see also BQ76952 datasheet). In order to allow the high currents, 4 MOSFETs are connected in parallel.

The bottom side of the PCB can be attached to a heat sink to dissipate the heat at high continuous

currents.

The cell connector has a pin to trigger a fuse at the pack positive terminal as a secondary protection if the MOSFETs fail short.

### 3.2.6 Current measurement

The current is measured using a shunt, located in the negative voltage path of the battery pack. The shunt voltage is amplified by the BQ76952 ASIC and read by the MCU.

Time-critical safety features like overcurrent and short circuit protection are implemented directly in the ASIC and can be calibrated via firmware.

### 3.2.7 Cell and thermistor connectors

The cells and thermistors are connected to the BMS using Molex Micro-Fit (https://www.molex.com/molex/products/family/microfit_30) or Würth WR-MPC3 (https://www.we-online.com/katalog/en/em/connectors/wire-to-board/wr_mpc3) series

connectors.

Both series are pin-compatible and there are even more compatible connectors in the market for this popular series. The connectors can handle up to 5A, which is sufficient even for active balancing.

### 3.2.8 Power connectors

The BMS is designed for up to 100A continuous current, depending on ambient temperatures, heat sink and actually fitted MOSFETs.

Würth high-power solder terminals with M5 threads are used for wire-to-board connections.

Libre Solar | 10

Libre Solar BMS C1 | User Manual

### 3.3 Communication interfaces

One major advantage of an Open Source design is its extensibility and adaptation to specific require-

ments.

In order to provide the hardware interfaces required to add custom extensions, two options are offered. Communication between multiple BMSs or other devices like charge controllers can be achieved via CAN bus, while the addional interfaces like I2C and UART can be used for extension of the board with internal features like displays.

The MCU features built-in WiFi and Bluetooth communication.

The serial and Bluetooth communication interfaces use the ThingSet protocol (https://thingset.io/) by default, which allows to read measurement values from the BMS as well as store custom configuration.

### 3.4 Firmware

The firmware is based on Zephyr RTOS (https://www.zephyrproject.org/) and thus allows for easy integration of additional communication features. The latest Zephyr long-term support release is in the process of being certified for functional safety according to IEC 61508.

Amongst all features inherited from underlying Zephyr, the BMS firmware has the additional BMSspecific features:

- Monitoring and configuration using the ThingSet (https://thingset.io/) protocol (mapping to MQTT, CoAP and HTTP possible)

– Serial interface
– CAN bus
– I2C
– Bluetooth
– WiFi
- SOC estimation based on coulomb counting
- Configuration options

– Pack layout

* Cell chemistry (LiFePO4, NMC, NCA) * Nominal capacity
* Number of cells
* Thermistor type
* Shunt resistor
Libre Solar | 11

Libre Solar BMS C1 | User Manual

* Custom open circuit voltage (OCV) look-up table

– Protection

* Discharge short circuit limit (A)
* Discharge short circuit delay (us) * Discharge over-current limit (A) * Discharge over-current delay (ms) * Charge over-current limit (A)
* Charge over-current delay (ms) * Cell target charge voltage (V) * Cell discharge voltage limit (V)
* Cell over-voltage limit (V)
* Cell over-voltage error reset threshold (V) * Cell over-voltage delay (ms)
* Cell under-voltage limit (V)
* Cell under-voltage error reset threshold (V) * Cell under-voltage delay (ms)
* Discharge over-temperature (DOT) limit (°C) * Discharge under-temperature (DUT) limit (°C) * Charge over-temperature (COT) limit (°C)
* Charge under-temperature (CUT) limit (°C) * Temperature limit hysteresis (°C)

– Balancing

* Enable automatic balancing.
* Balancing cell voltage target difference (V) * Minimum cell voltage to start balancing (V) * Current threshold to be considered idle (A) * Minimum idle duration before balancing (s)
Libre Solar | 12

Libre Solar BMS C1 | User Manual

## 4 Installation

Attention: The maximum operating voltage of the BMS is 60V. The 16s configuration is only feasible for LFP cells. For NMC cells, a maximum number of 14 cells may be used.

### 4.1 Mechanical Design

The board dimensions are 70x135 mm2 so that it can be easily integrated into existing housings with

typical 18650 or 2170 cells.

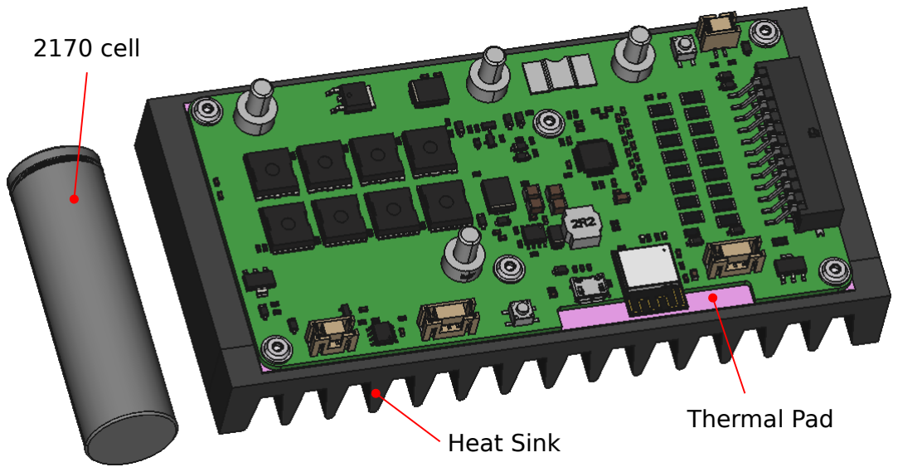
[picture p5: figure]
Thermal Pad; 2170 cell; Heat Sink

Figure 3: BMS mounted on a heat sink

Depending on the current requirements and ambient temperatures, a heat sink may be required. For good thermal contact, a thermal interface material (e.g. Henkel/Bergquist GAP PAD A2000) is required, as shown in above picture.

### 4.2 Connections

Below picture shows the connections of the cells, the 10k thermistors (NTC1 and NTC2) and the high power cables.

Libre Solar | 13

Libre Solar BMS C1 | User Manual

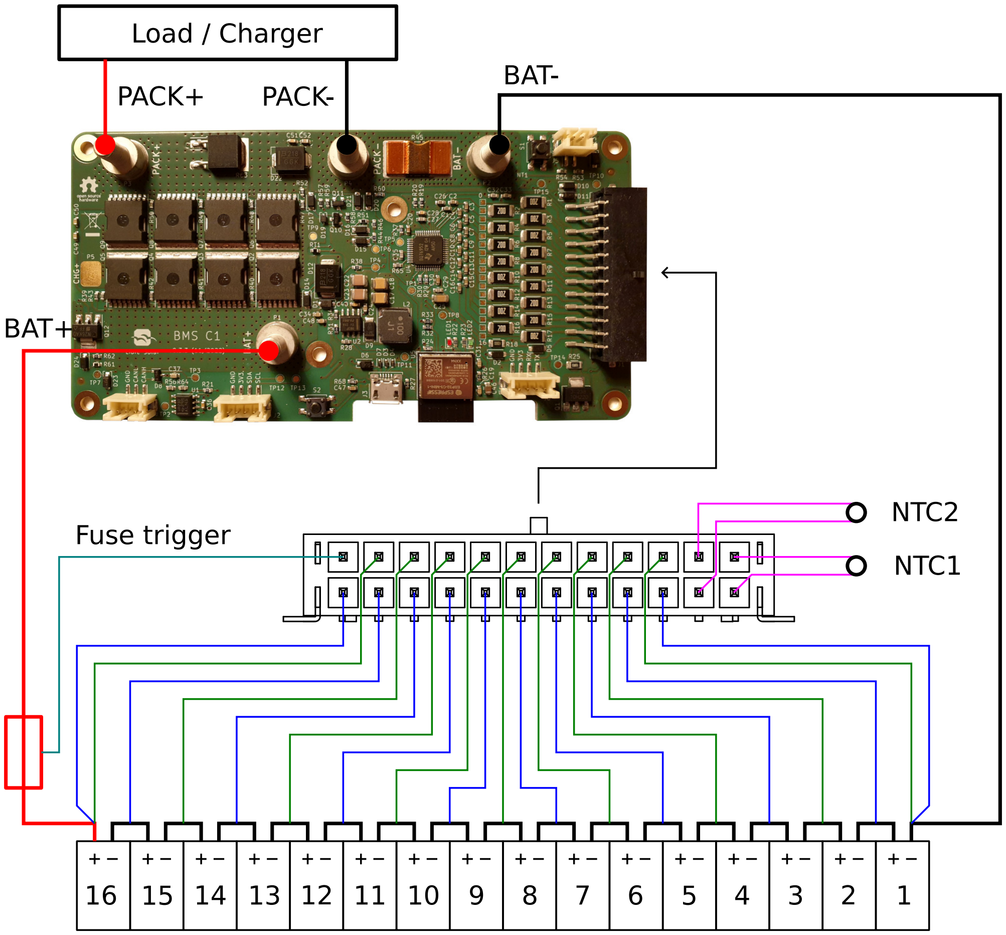
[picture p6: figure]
Load / Charger; NTC2; NTC1; Fuse trigger; BAT-; BAT+; PACK+; PACK-

Figure 4: BMS connections

The BMS is powered through the BAT+ terminal. If only the cell connector is mounted, the power is provided through the additional BAT+ wire in the cell connector, which has to be connected to the last cell’s positive terminal.

The BMS cannot be powered through the USB port only.

### 4.2.1 Power connections

The high power terminals have an M5 thread and allow to fit wires of up to 35 mm2 cross-section.

Libre Solar | 14

Libre Solar BMS C1 | User Manual

The nuts and washers should be made from stainless steel to avoid corrosion with copper cable lugs.

The wires must be properly fixed in the housing to reduce stress on the soldered terminals on the

PCB.

The fixing torque for the nuts is 2.2 Nm. Use of a torque wrench is highly recommended.

### 4.2.2 Signal connections

The MPC3 / Microfit connector must be equipped with properly crimped wires connected to the cells and the thermistors. Würth sells pre-crimped wires (https://www.we-online.com/de/components/products/em/connectors/wire-to-board/wr_mpc3/wr_mpc3_pre_crimped_wire) so that no crimping tool is needed (the low-force type is recommended). These wires can be cut in half and connected to an own wiring harness.

If less than 16 cells are used, the unused cell connections have to be short-circuited (either on the PCB using the pads left of the balancing resistors or in the wiring harness). See also the BQ76952 documentation (https://www.ti.com/product/BQ76952) for further details.

At least NTC1 has to be connected and show a valid temperature range for the BMS to allow charging/discharging.

### 4.2.3 Connection order

1. Connect the fully wired cell connector. (Note the two separate connections to the first cell’s negative terminal)
2. Connect the BAT- terminal.
3. Connect the BAT+ terminal (with a fuse in line, as shown).
4. Connect load or charger.

### 4.3 Communication ports

The CAN, UART and I2C communication ports use JST PH connectors. The pinout is marked on the

PCB.

The I2C is shared with the BQ76952. It must be ensured that this communication is not disturbed by another component on the I2C bus.

Libre Solar | 15

Libre Solar BMS C1 | User Manual

## 5 Operation

### 5.1 Firmware flashing

If no firmware is flashed on the board, make sure the board is powered through the cell connector. The power wires BAT+ and BAT- are optional.

The firmware is flashed through the USB port. Follow the instructions in the Firmware repository. (https://github.com/LibreSolar/bms-firmware)

### 5.2 Start-up

In order to wake up the BMS chip, short-press the ON/OFF button S1 (top-right corner).

If the button is long-pressed for at least 3 seconds, the BMS will go into low-power shutdown mode.

A custom push-button as part of the battery housing can be connected to the connector J5 next to the button.

### 5.3 LED indications

The BMS is equipped with two status LEDs with below indications:

Red LED:

Status | Meaning
off | Discharging finished and battery is empty
on | Discharging allowed (current below idle threshold)
blinking slowly | Discharging active (current above idle threshold)
flashing quickly | Discharging error (UV/OT/UT/OC/SC)

Green LED:

Status | Meaning
off | Charging finished and battery is full
on | Charging allowed (current below idle threshold)
blinking slowly | Charging active (current above idle threshold)
Libre Solar | 16

Libre Solar BMS C1 | User Manual
Status | Meaning
flashing quickly | Charging error (OV/OT/UT/OC)

### 5.4 Communication Setup

Device information, configuration values and measurements can be explored using the ThingSet protocol. (https://thingset.io/) This protocol is used for the serial interface as well as the Bluetooth communication.

For details regarding the protocol consider the specification linked above. The basic setup is explained below.

### 5.4.1 USB Serial

The USB virtual COM port exposes log data and the Zephyr shell. Among other commands, the shell can also be used for communication using the ThingSet protocool.

A terminal program like picocom is recommended:

picocom /dev/ttyACM0

The shell command for the ThingSet protocol is thingset. Either prefix it for every command or select thingset to switch into ThingSet mode.

select thingset
?Meas
:85 {"rPackVoltage_V":13.71,"rStackVoltage_V":13.91,"rPackCurrent_A":0.05, "rBatTemp_degC":29.4,"rICTemp_degC":34.2,"rMOSFETTemp_degC":31.8," rSOC_pct":100.0,"rErrorFlags":0,"rBmsState":3,"rCellVoltages_V" :[3.495,3.497,3.486,3.495,0.000,0.000,0.000,0.000,0.000,0.000,0.000,0.000,0.000,0.000,0.000,0.000], "rCellAvgVoltage_V":3.493,"rCellMinVoltage_V":3.486,"rCellMaxVoltage_V" :3.497,"rBalancingStatus":0}

When using the shell, the quotation marks in JSON data have to be escaped. See below for an example:

=Conf {\"sCellOvervoltage_V\": 3.8}
:84
Libre Solar | 17

Libre Solar BMS C1 | User Manual

### 5.4.2 UART Serial

The serial interface uses a baud-rate of 115200 bps. Depending on the operating system, you can use different tools to communicate with the serial interface manually.

For Linux CuteCom (https://sourceforge.net/projects/cutecom/) is recommended, as it stores a history of previous commands.

The Serial2Websocket Python script (https://github.com/ThingSet/thingset-serial2websocket) can be used as a basis for own scripts to use the monitoring data.

### 5.4.3 BLE

The generic ThingSet app (https://github.com/ThingSet/thingset-app) can be used to connect to the BMS via Bluetooth LE.

For own developments see the BLE transport layer specification on the ThingSet website and consider the implementation of the device side in the ThingSet Zephyr SDK. (https://github.com/ThingSet/thingset-zephyr-sdk)

### 5.5 Configuration

The ThingSet protocol itself allows to discover available data items for configuration, so this manual will only use some examples for demonstration purposes.

### 5.5.1 Read measurements and battery status

Use the following command to get the current state of the battery, including all current, temperature and voltage measurements:

?Meas

### 5.5.2 Configure battery type

The configuration for a particular cell type and battery size can be preset with suitable default values using the two executable data items xPresetNMC for NMC cells and xPresetLFP for LFP cells. The functions expect a parameter defining the nominal capacity of the battery in Ah.

For an LFP battery with 45 Ah, send the following command to the BMS:

!Conf/xPresetLFP [45]

The expected response if the parameters were successfully set:

:84 0

Libre Solar | 18

Libre Solar BMS C1 | User Manual

### 5.5.3 Adjust thresholds

The current configuration can be determined with the following command:

?Conf

Individual parameters can be adjusted with a command as shown below (using the overvoltage threshold as an example):

=Conf {"sCellOvervoltage_V": 3.8}

Libre Solar | 19

Libre Solar BMS C1 | User Manual

## 6 Datasheet

Feature | Value | Comment

Battery

Nominal voltage range | 12 V to 48 V
Maximum voltage | 60 V | (only 14s for NMC allowed)
Maximum current | 70 A - 100 A | Depending on ambient conditions and heat sink
Self consumption | < 20 mA | Exact value t.b.d.
Shutdown current | < 1 mA | Exact value t.b.d.
Cell types | LFP, NMC and others | Customizable through firmware

Interfaces

CAN 2.0

USB CDC-ACM

UART serial

I2C

Bluetooth

Protection

Over-/undervoltage

Overcurrent / Short circuit

Over-/undertemperature

Environmental conditions

Operating ambient temperature | -10 °C to +50 °C
Storage temperature | -20 °C to +60 °C
Humidity | <95%, non-condensing

Mechanical design

Screw terminals | M5, torque: 2.2 Nm
Weight | t.b.d.
Dimensions | 70 mm x 135 mm
Libre Solar | 20

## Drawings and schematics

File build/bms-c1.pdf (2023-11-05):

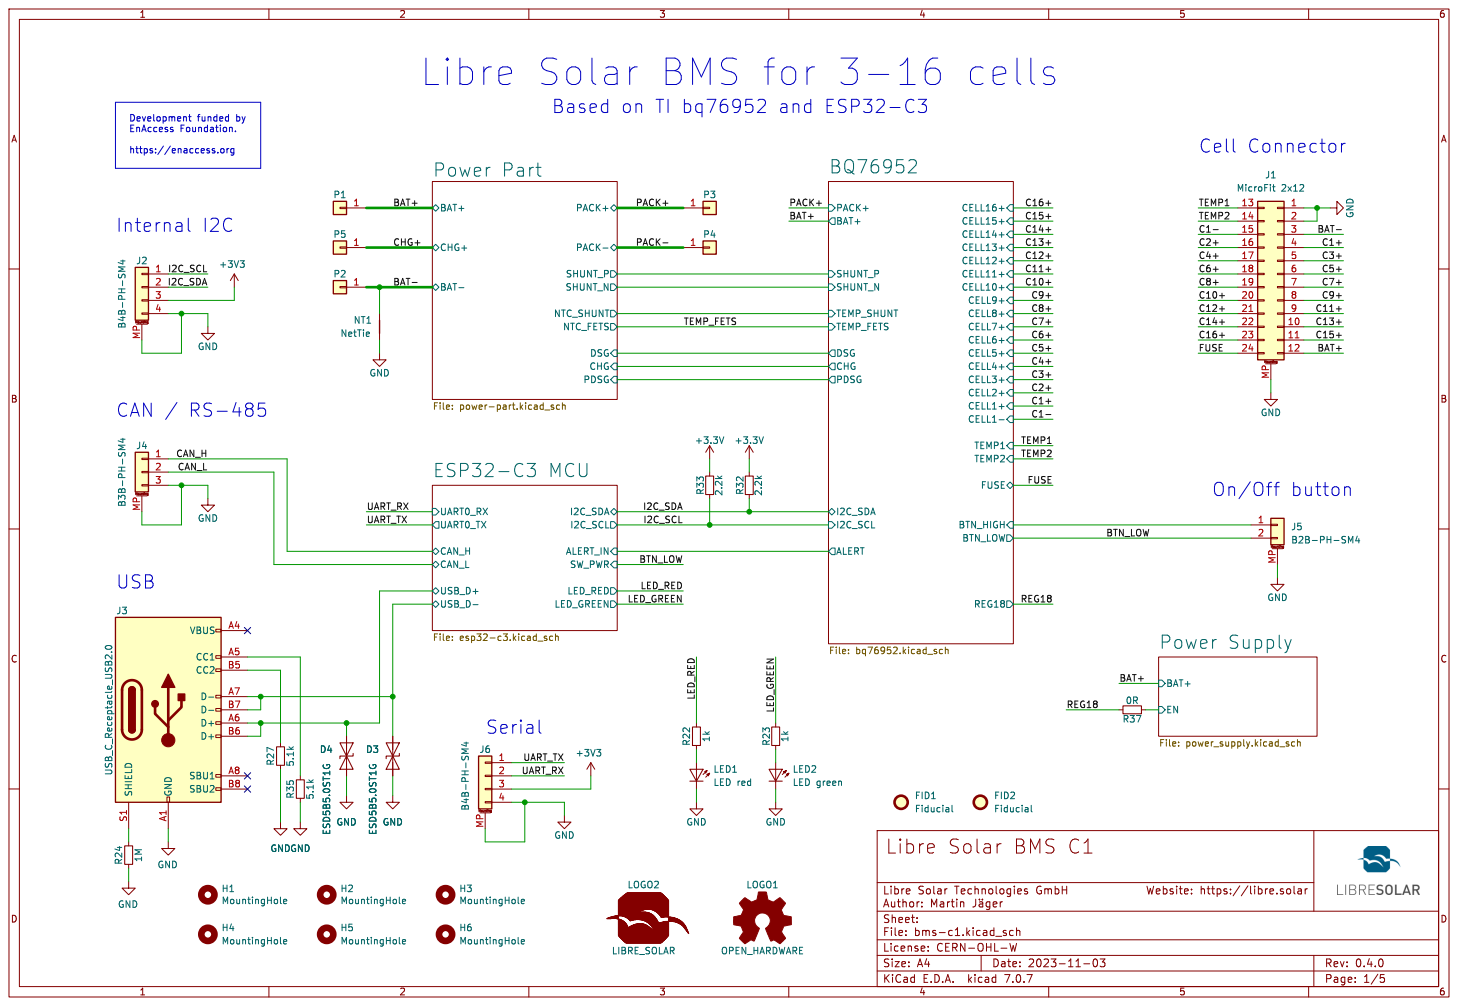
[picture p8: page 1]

Based on TI bq76952 and ESP32-C3

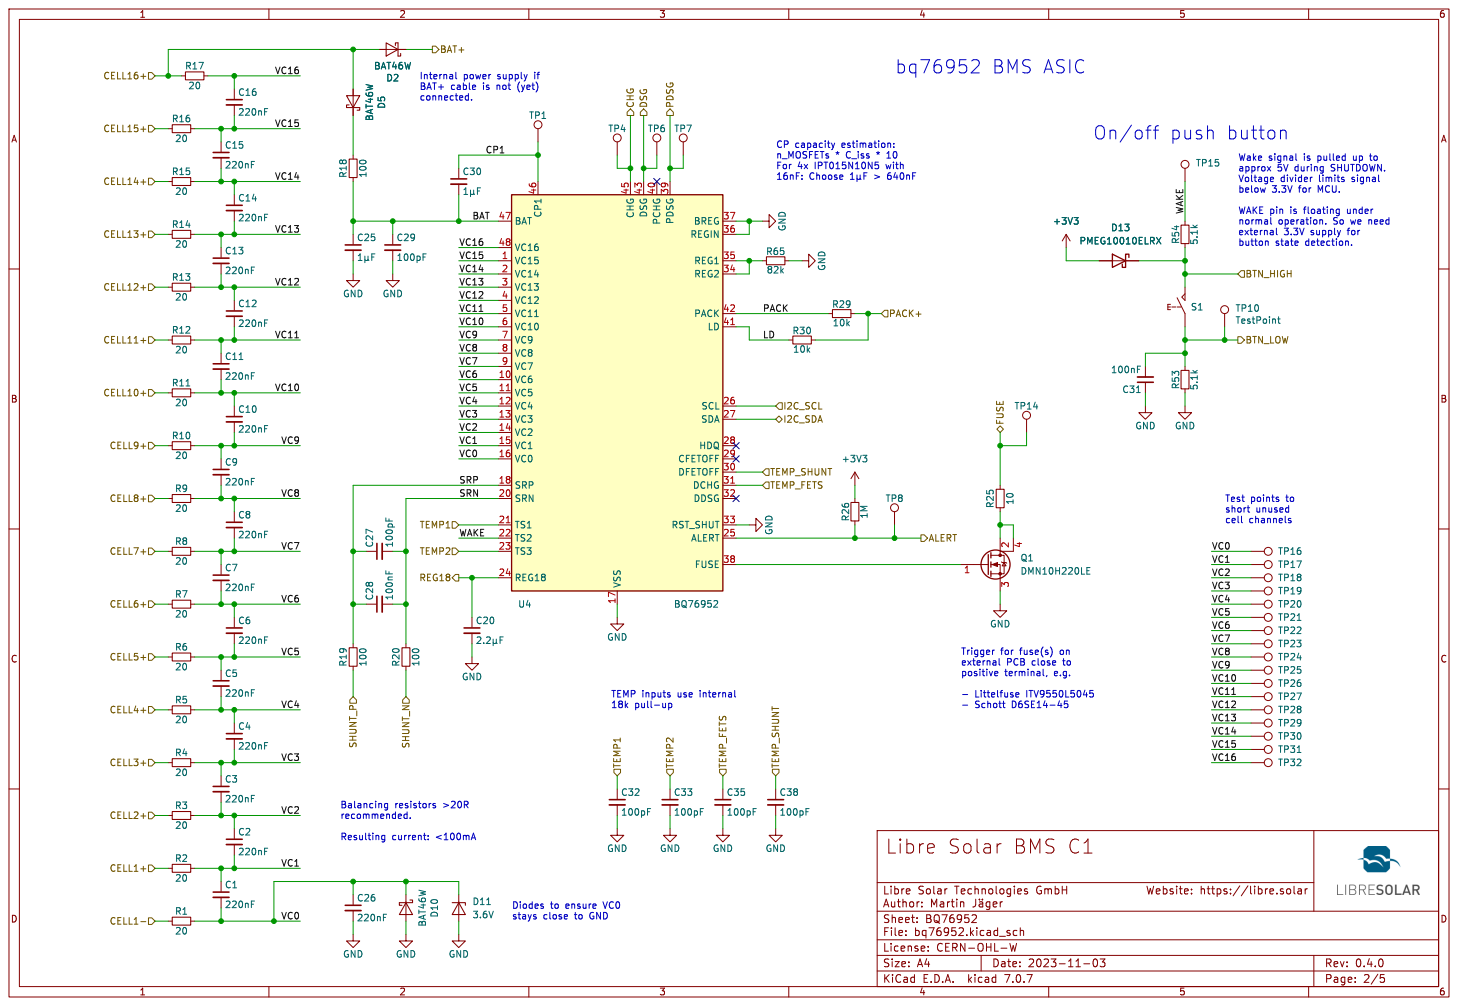
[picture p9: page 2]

cell channels Diodes to ensure VC0

TEMP inputs use internal 18k pull-up

stays close to GND

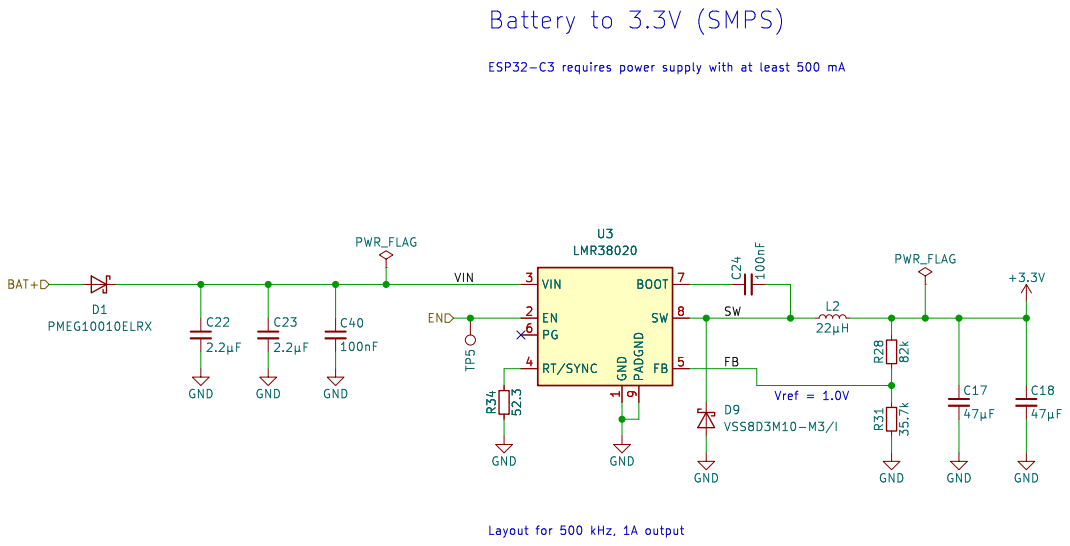
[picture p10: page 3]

1 EN 2 VIN 3 RT/SYNC 4 FB 5 PG 6 BOOT 7 SW 8 PADGND

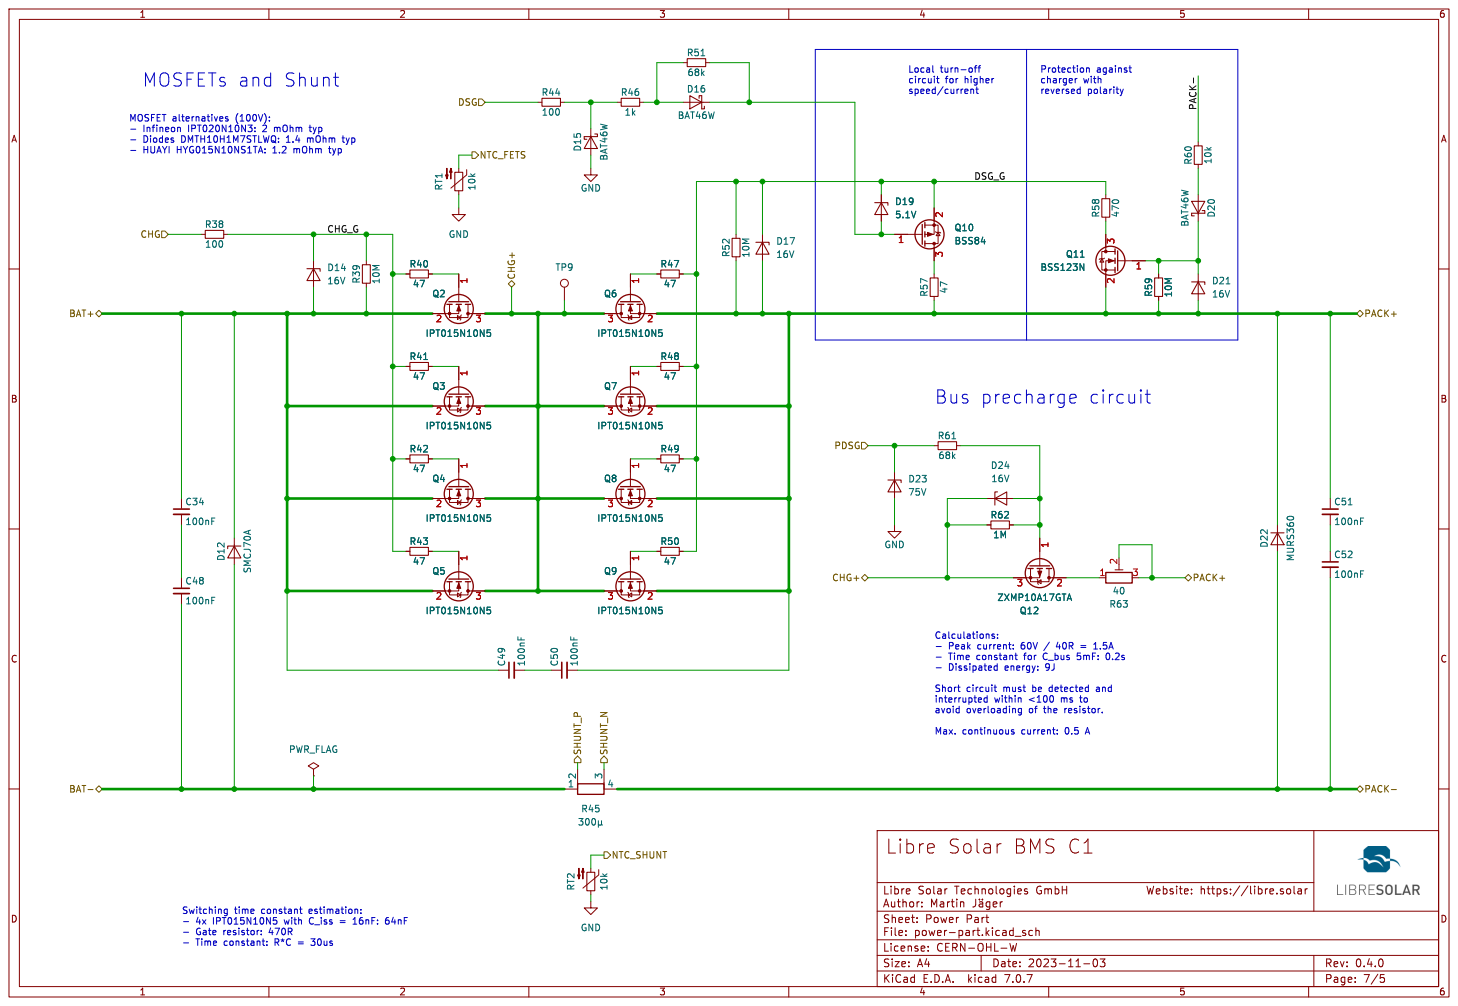
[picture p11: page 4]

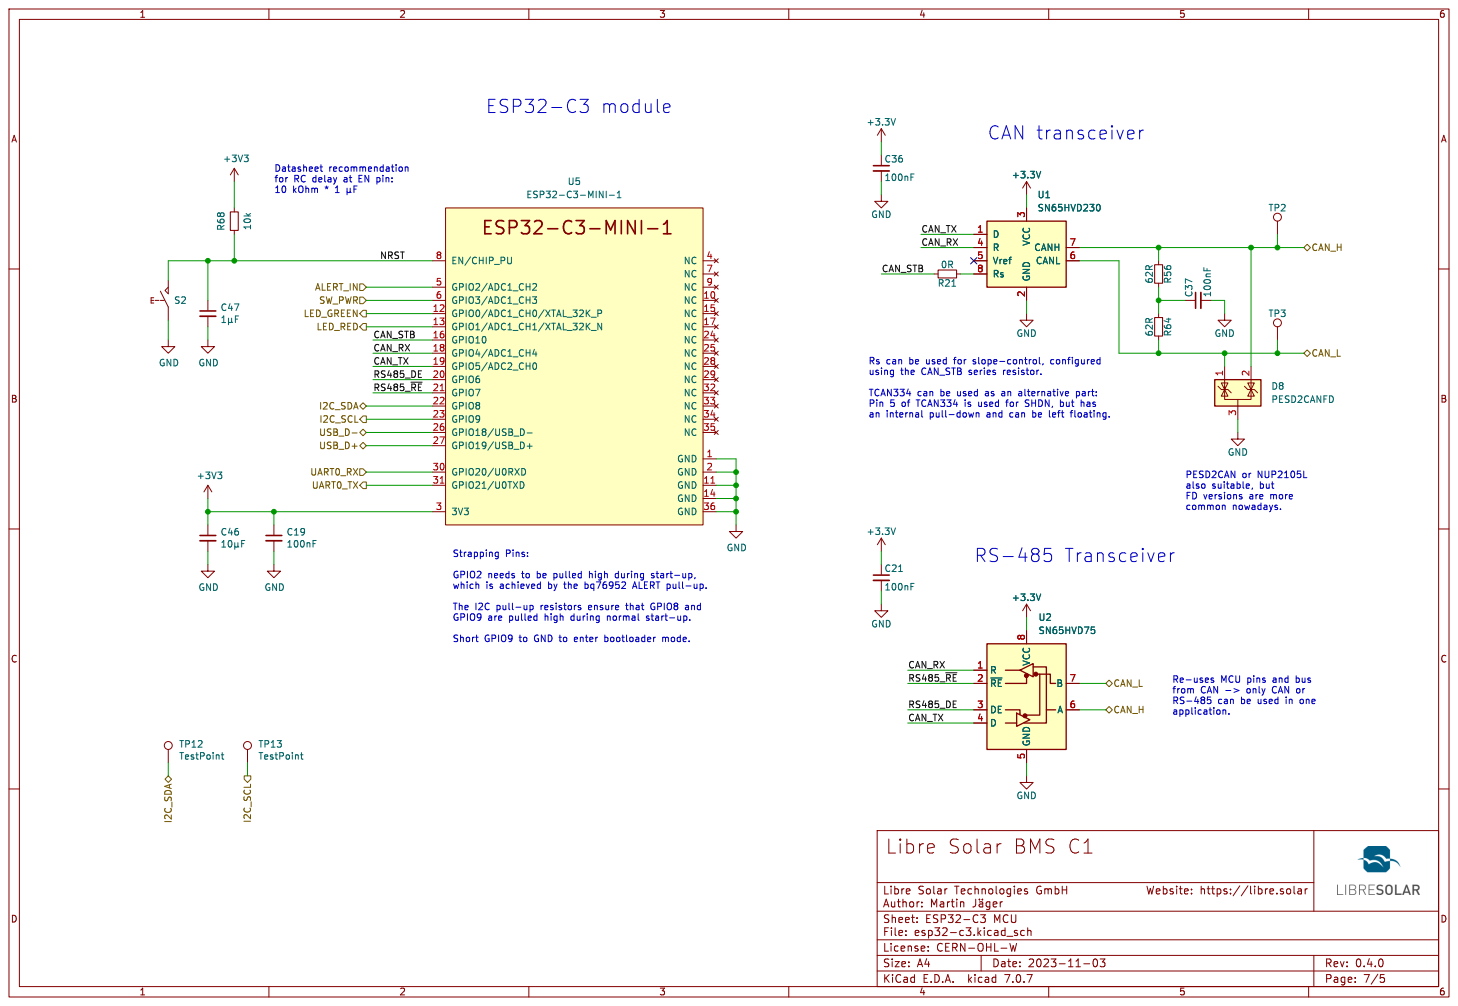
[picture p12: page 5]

for RC delay at EN pin: 10 kOhm * 1 þÿµF

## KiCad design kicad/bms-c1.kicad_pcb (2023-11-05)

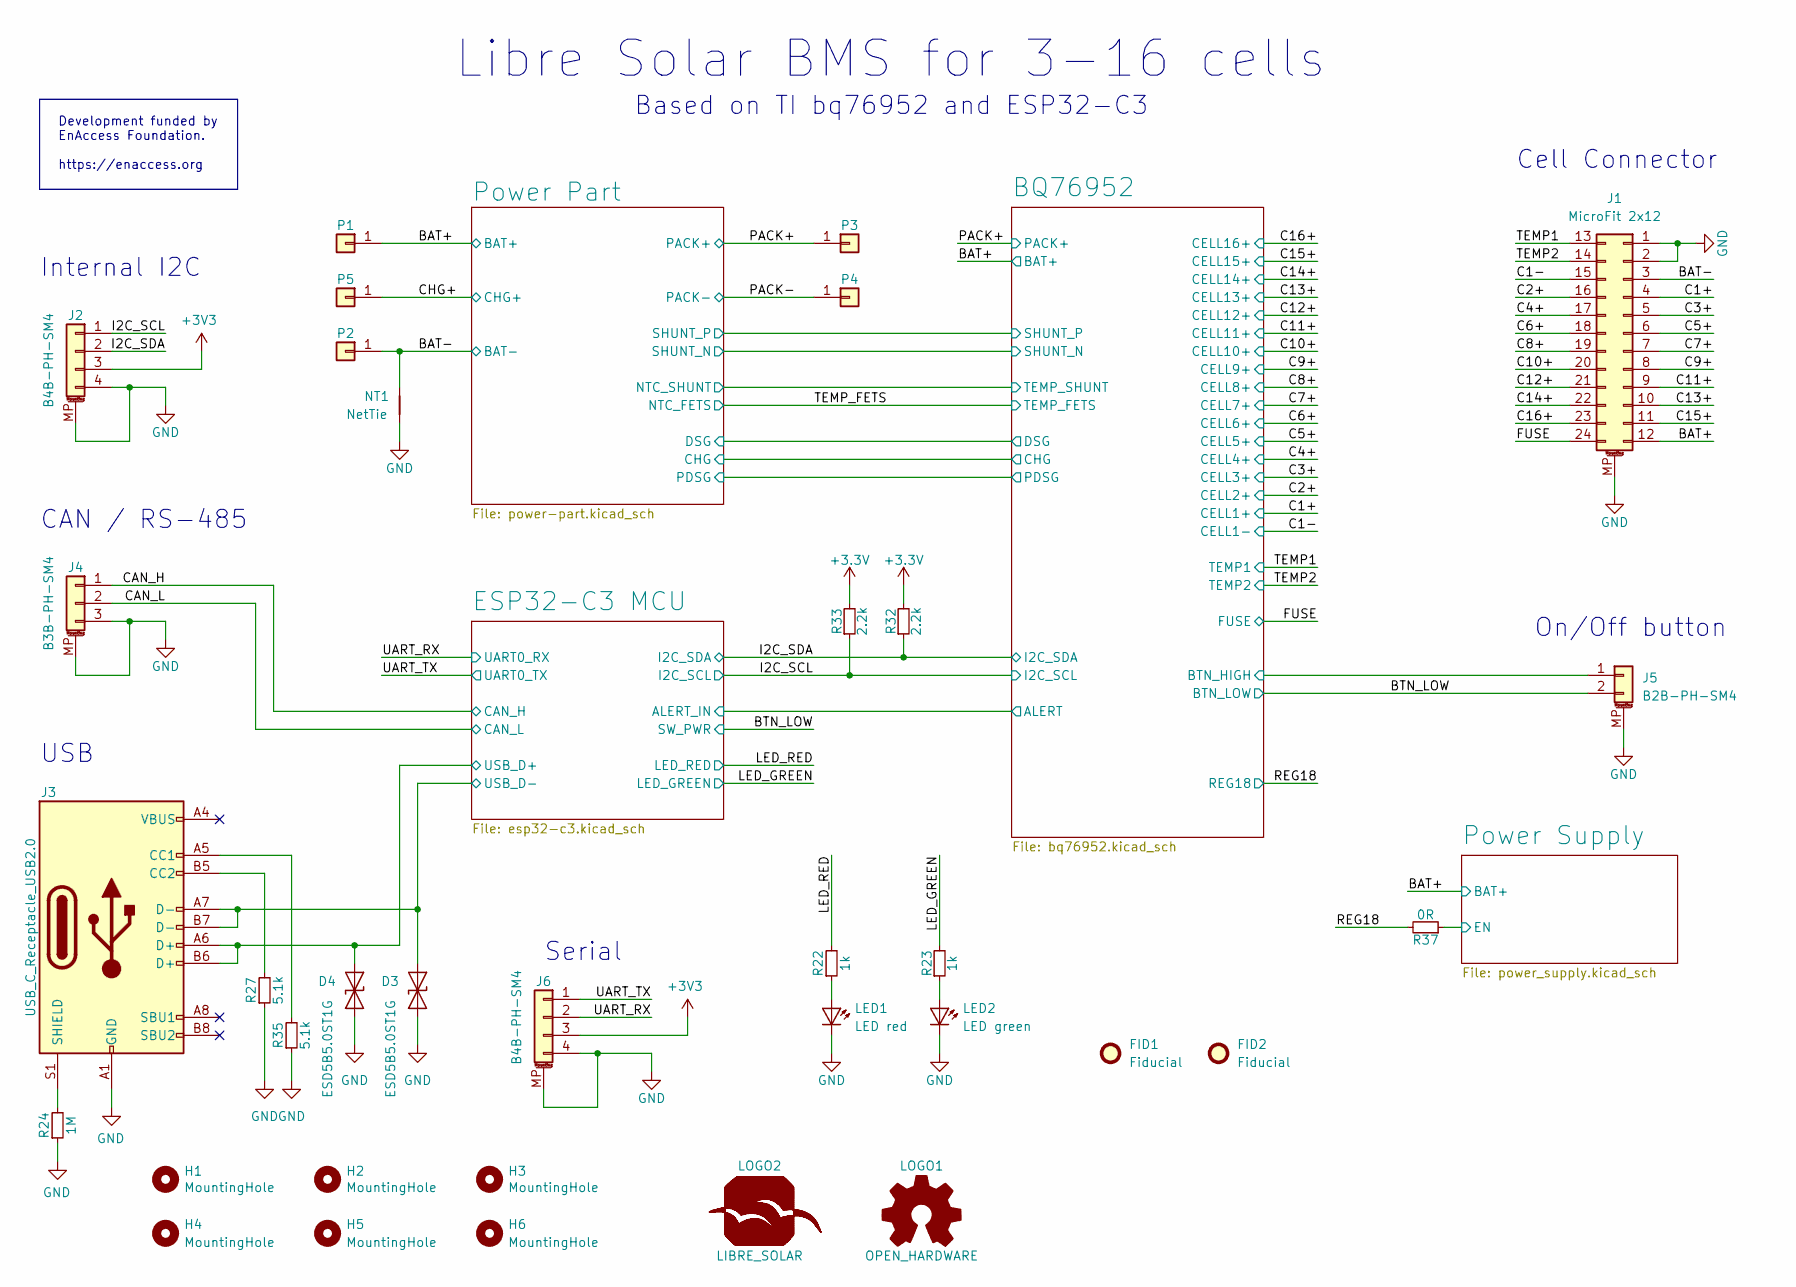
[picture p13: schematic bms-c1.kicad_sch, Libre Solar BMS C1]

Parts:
D3, D4: ESD5B5.0ST1G; D_SOD-523; PartNumber ESD5B5.0ST1G
FID1, FID2: Fiducial; Fiducial_1mm_Mask2mm
H1, H2, H3, H4, H5, H6: MountingHole; MountingHole_3.2mm_M3_Pad_TopBottom
J1: MicroFit 2x12; Molex_Micro-Fit_3.0_43045-2410_2x12-1MP_P3.00mm_Horizontal; PartNumber 662024231722
J2, J6: B4B-PH-SM4; JST_PH_B4B-PH-SM4-TB_1x04-1MP_P2.00mm_Vertical; PartNumber B4B-PH-SM4-TB(LF)(SN)
J3: USB_C_Receptacle_USB2.0; USB_C_Receptacle_GCT_USB4105-xx-A_16P_TopMnt_Horizontal; PartNumber USB4105-GF-A
J4: B3B-PH-SM4; JST_PH_B3B-PH-SM4-TB_1x03-1MP_P2.00mm_Vertical; PartNumber B3B-PH-SM4-TB(LF)(SN)
J5: B2B-PH-SM4; JST_PH_B2B-PH-SM4-TB_1x02-1MP_P2.00mm_Vertical; PartNumber B2B-PH-SM4-TB(LF)(SN)
LED1: LED red; LED_0603_1608Metric
LED2: LED green; LED_0603_1608Metric
LOGO1: OPEN_HARDWARE; OSHW-Logo_5.7x6mm_SilkScreen
LOGO2: LIBRE_SOLAR; LIBRESOLAR_LOGO
NT1: NetTie; NetTie-2_SMD_Pad0.5mm
P1, P2, P3, P4: CONN_01X01; Wuerth_WP-SMBU_7466005R; PartNumber 7466005R
P5: CONN_01X01; SolderWirePad_1x01_SMD_5x10mm
R22, R23: 1k; R_0603_1608
R24: 1M; R_0603_1608
R27, R35: 5.1k; R_0603_1608
R32, R33: 2.2k; R_0603_1608
R37: 0R; R_0603_1608

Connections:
/BAT+: J1.12, P1.1; also elsewhere on the board
/BAT-: J1.3, NT1.1, P2.1; also elsewhere on the board
/BQ76952/BTN_HIGH: J5.1; also elsewhere on the board
/BTN_LOW: J5.2; also elsewhere on the board
/C1+: J1.4; also elsewhere on the board
/C1-: J1.15; also elsewhere on the board
/C2+: J1.16; also elsewhere on the board
/C3+: J1.5; also elsewhere on the board
/C4+: J1.17; also elsewhere on the board
/C5+: J1.6; also elsewhere on the board
/C6+: J1.18; also elsewhere on the board
/C7+: J1.7; also elsewhere on the board
/C8+: J1.19; also elsewhere on the board
/C9+: J1.8; also elsewhere on the board
/C10+: J1.20; also elsewhere on the board
/C11+: J1.9; also elsewhere on the board
/C12+: J1.21; also elsewhere on the board
/C13+: J1.10; also elsewhere on the board
/C14+: J1.22; also elsewhere on the board
/C15+: J1.11; also elsewhere on the board
/C16+: J1.23; also elsewhere on the board
/CAN_H: J4.1; also elsewhere on the board
/CAN_L: J4.2; also elsewhere on the board
/CHG+: P5.1; also elsewhere on the board
/ESP32-C3 MCU/USB_D+: D4.2 (A2), J3.A6 (D+), J3.B6 (D+); also elsewhere on the board
/ESP32-C3 MCU/USB_D-: D3.2 (A2), J3.A7 (D-), J3.B7 (D-); also elsewhere on the board
/FUSE: J1.24; also elsewhere on the board
/I2C_SCL: J2.1, R33.1; also elsewhere on the board
/I2C_SDA: J2.2, R32.1; also elsewhere on the board
/LED_GREEN: R23.2; also elsewhere on the board
/LED_RED: R22.2; also elsewhere on the board
/PACK+: P3.1; also elsewhere on the board
/PACK-: P4.1; also elsewhere on the board
/Power Supply/EN: R37.1; also elsewhere on the board
/REG18: R37.2; also elsewhere on the board
/TEMP1: J1.13; also elsewhere on the board
/TEMP2: J1.14; also elsewhere on the board
/UART_RX: J6.2; also elsewhere on the board
/UART_TX: J6.1; also elsewhere on the board
GND: D3.1 (A1), D4.1 (A1), J1.1, J1.2, J1.MP (MountPin), J2.4, J2.MP (MountPin), J3.A1 (GND), J3.A12 (GND), J3.B1 (GND), J3.B12 (GND), J4.3, J4.MP (MountPin), J5.MP (MountPin), J6.4, J6.MP (MountPin), LED1.1 (K), LED2.1 (K), NT1.2, R24.1, R27.1, R35.1; also elsewhere on the board
unnamed: J3.A5 (CC1), R35.2
unnamed: J3.B5 (CC2), R27.2
unnamed: J3.S1 (SHIELD), R24.2
unnamed: LED1.2 (A), R22.1
unnamed: LED2.2 (A), R23.1

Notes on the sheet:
Based on TI bq76952 and ESP32-C3
CAN / RS-485
Development funded by EnAccess Foundation. https://enaccess.org
USB
Serial
Libre Solar BMS for 3-16 cells
Cell Connector
Internal I2C
On/Off button

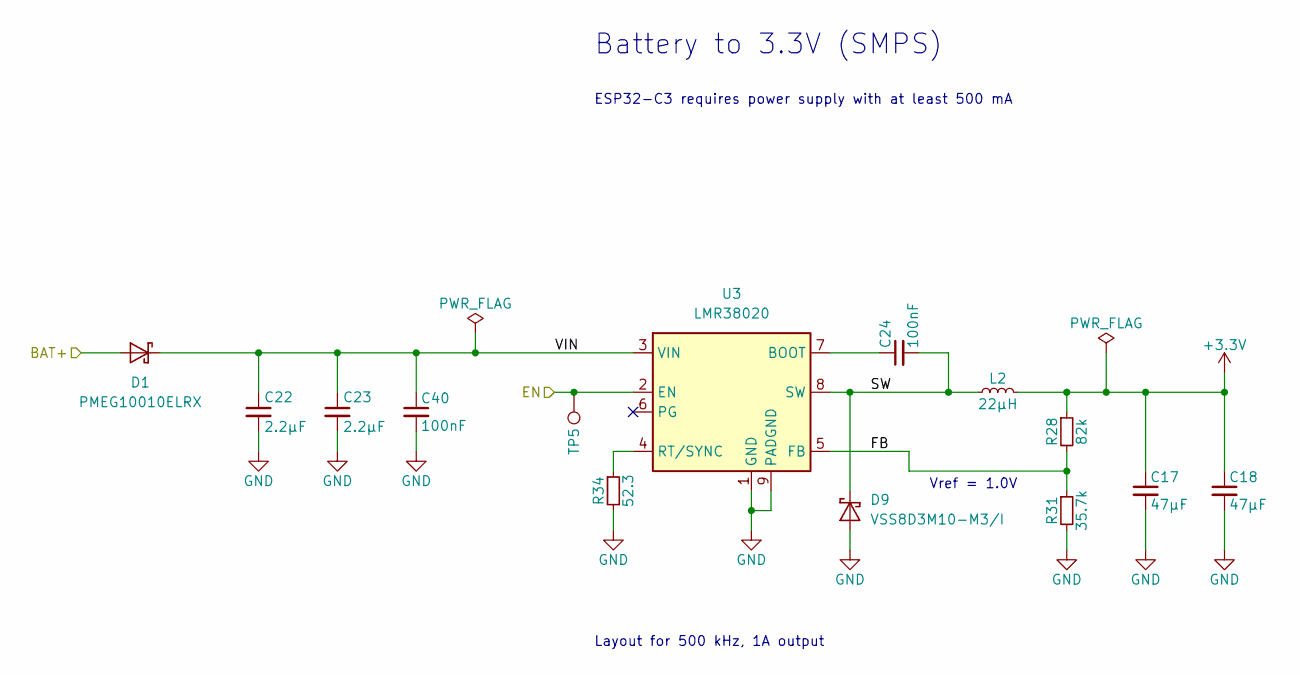
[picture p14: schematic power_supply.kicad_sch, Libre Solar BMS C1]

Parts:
C17, C18: 47µF; C_1210_3225; PartNumber CL32B476MPJNNNE
C22, C23: 2.2µF; C_1210_3225
C24, C40: 100nF; C_0603_1608
D1: PMEG10010ELRX; D_SOD-123F; PartNumber PMEG10010ELRX
D9: VSS8D3M10-M3/I; D_SOD-128; PartNumber VSS8D3M10-M3/I
L2: 22µH; Bourns_SRN8040TA; PartNumber NR8040T100M
R28: 82k; R_0603_1608
R31: 35.7k; R_0603_1608
R34: 52.3; R_0603_1608
TP5: TestPoint; TestPoint_Pad_D1.5mm
U3: LMR38020; SOIC-8-1EP_3.9x4.9mm_P1.27mm_EP2.4x3.1mm_ThermalVias; PartNumber LMR38020SDDAR

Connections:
/BAT+: D1.2 (A); also elsewhere on the board
/Power Supply/EN: TP5.1, U3.2 (EN); also elsewhere on the board
/Power Supply/FB: R28.2, R31.1, U3.5 (FB)
/Power Supply/SW: C24.2, D9.1 (K), L2.1, U3.8 (SW)
/Power Supply/VIN: C22.1, C23.1, C40.1, D1.1 (K), U3.3 (VIN)
GND: C17.2, C18.2, C22.2, C23.2, C40.2, D9.2 (A), R31.2, R34.2, U3.1 (GND), U3.9 (PADGND); also elsewhere on the board
unnamed: C24.1, U3.7 (BOOT)
unnamed: R34.1, U3.4 (RT/SYNC)

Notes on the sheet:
ESP32-C3 requires power supply with at least 500 mA
Layout for 500 kHz, 1A output
Battery to 3.3V (SMPS)
Vref = 1.0V

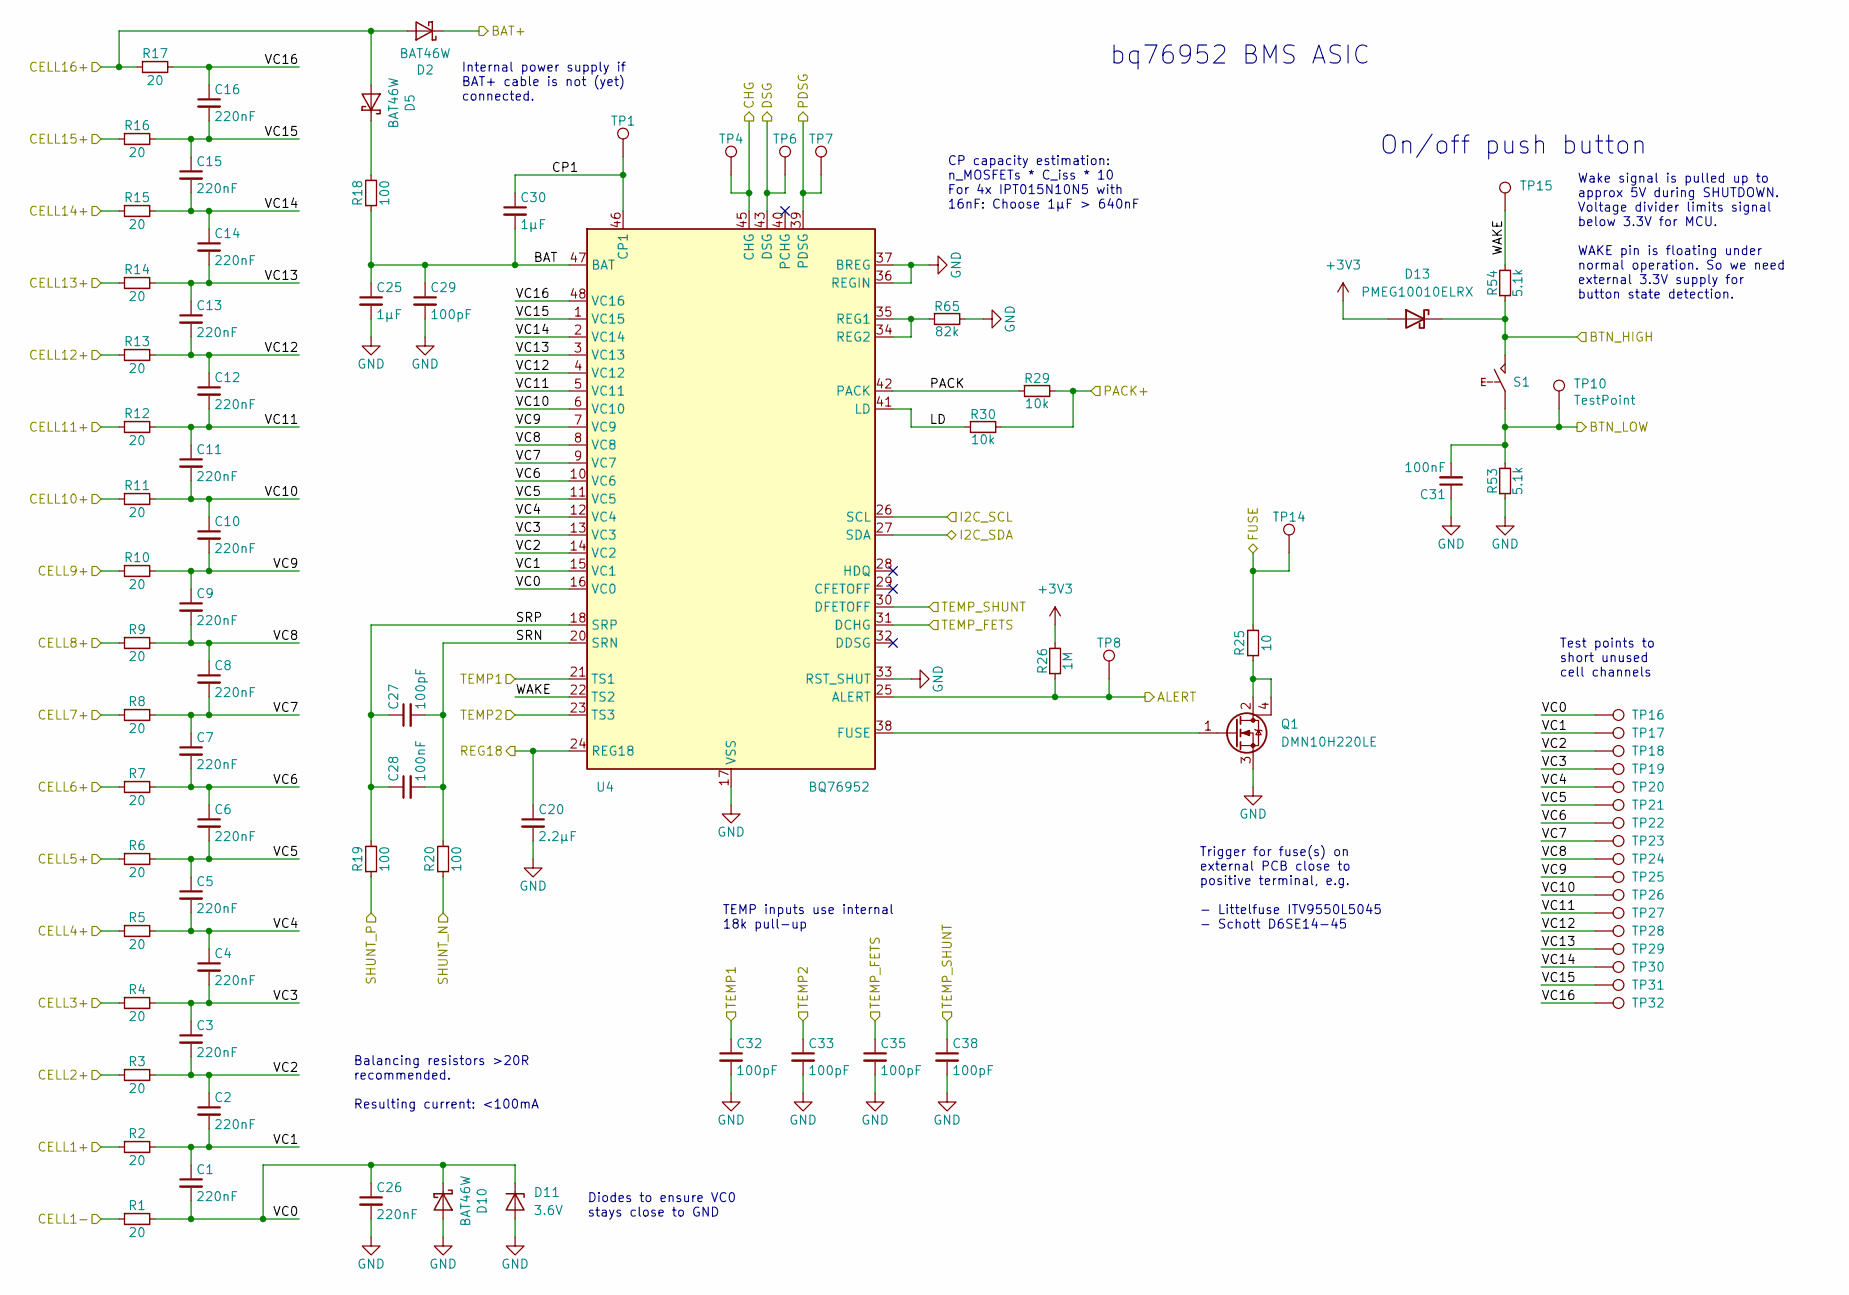
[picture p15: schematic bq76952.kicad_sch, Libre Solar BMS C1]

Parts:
C1, C2, C3, C4, C5, C6, C7, C8, C9, C10, C11, C12, C13, C14, C15, C16, C26: 220nF; C_0603_1608
C20: 2.2µF; C_0603_1608
C25: 1µF; C_1206_3216
C27, C29, C32, C33, C35, C38: 100pF; C_0603_1608
C28, C31: 100nF; C_0603_1608
C30: 1µF; C_0603_1608
D2, D5, D10: BAT46W; D_SOD-123; PartNumber BAT46W-7-F
D11: 3.6V; D_SOD-123; PartNumber MMSZ4685T1G
D13: PMEG10010ELRX; D_SOD-123F; PartNumber PMEG10010ELRX
Q1: DMN10H220LE; SOT-223; PartNumber DMN10H220LE
R1, R2, R3, R4, R5, R6, R7, R8, R9, R10, R11, R12, R13, R14, R15, R16, R17: 20; R_2010_5025; PartNumber RC2010JK-0720RL
R18: 100; R_1206_3216
R19, R20: 100; R_0603_1608
R25: 10; R_1206_3216
R26: 1M; R_0603_1608
R29, R30: 10k; R_0603_1608
R53, R54: 5.1k; R_0603_1608
R65: 82k; R_0603_1608
S1: SW_PUSH; SW_SPST_TL3305A; PartNumber TL3305AF160QG
TP1, TP4, TP6, TP7, TP8, TP10, TP14, TP15: TestPoint; TestPoint_Pad_D1.5mm
TP16, TP17, TP18, TP19, TP20, TP21, TP22, TP23, TP24, TP25, TP26, TP27, TP28, TP29, TP30, TP31, TP32: TestPoint; TestPoint_Pad_1.0x1.0mm
U4: BQ76952; TQFP-48_7x7mm_P0.5mm; PartNumber BQ76952PFBR

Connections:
/BAT+: D2.1 (K); also elsewhere on the board
/BQ76952/ALERT: R26.1, TP8.1, U4.25 (ALERT); also elsewhere on the board
/BQ76952/BAT: C25.1, C29.1, C30.2, R18.1, U4.47 (BAT)
/BQ76952/BTN_HIGH: D13.1 (K), R54.1, S1.2; also elsewhere on the board
/BQ76952/CHG: TP4.1, U4.45 (CHG); also elsewhere on the board
/BQ76952/CP1: C30.1, TP1.1, U4.46 (CP1)
/BQ76952/DSG: TP6.1, U4.43 (DSG); also elsewhere on the board
/BQ76952/LD: R30.1, U4.41 (LD)
/BQ76952/PACK: R29.1, U4.42 (PACK)
/BQ76952/PDSG: TP7.1, U4.39 (PDSG); also elsewhere on the board
/BQ76952/SHUNT_N: R20.1; also elsewhere on the board
/BQ76952/SHUNT_P: R19.1; also elsewhere on the board
/BQ76952/SRN: C27.2, C28.2, R20.2, U4.20 (SRN)
/BQ76952/SRP: C27.1, C28.1, R19.2, U4.18 (SRP)
/BQ76952/TEMP_SHUNT: C38.1, U4.30 (DFETOFF); also elsewhere on the board
/BQ76952/VC0: C1.2, C26.1, D10.1 (K), D11.1 (K), R1.2, TP16.1, U4.16 (VC0)
/BQ76952/VC1: C1.1, C2.2, R2.2, TP17.1, U4.15 (VC1)
/BQ76952/VC2: C2.1, C3.2, R3.2, TP18.1, U4.14 (VC2)
/BQ76952/VC3: C3.1, C4.2, R4.2, TP19.1, U4.13 (VC3)
/BQ76952/VC4: C4.1, C5.2, R5.2, TP20.1, U4.12 (VC4)
/BQ76952/VC5: C5.1, C6.2, R6.2, TP21.1, U4.11 (VC5)
/BQ76952/VC6: C6.1, C7.2, R7.2, TP22.1, U4.10 (VC6)
/BQ76952/VC7: C7.1, C8.2, R8.2, TP23.1, U4.9 (VC7)
/BQ76952/VC8: C8.1, C9.2, R9.2, TP24.1, U4.8 (VC8)
/BQ76952/VC9: C9.1, C10.2, R10.2, TP25.1, U4.7 (VC9)
/BQ76952/VC10: C10.1, C11.2, R11.2, TP26.1, U4.6 (VC10)
/BQ76952/VC11: C11.1, C12.2, R12.2, TP27.1, U4.5 (VC11)
/BQ76952/VC12: C12.1, C13.2, R13.2, TP28.1, U4.4 (VC12)
/BQ76952/VC13: C13.1, C14.2, R14.2, TP29.1, U4.3 (VC13)
/BQ76952/VC14: C14.1, C15.2, R15.2, TP30.1, U4.2 (VC14)
/BQ76952/VC15: C15.1, C16.2, R16.2, TP31.1, U4.1 (VC15)
/BQ76952/VC16: C16.1, R17.2, TP32.1, U4.48 (VC16)
/BQ76952/WAKE: R54.2, TP15.1, U4.22 (TS2)
/BTN_LOW: C31.2, R53.2, S1.1, TP10.1; also elsewhere on the board
/C1+: R2.1; also elsewhere on the board
/C1-: R1.1; also elsewhere on the board
/C2+: R3.1; also elsewhere on the board
/C3+: R4.1; also elsewhere on the board
/C4+: R5.1; also elsewhere on the board
/C5+: R6.1; also elsewhere on the board
/C6+: R7.1; also elsewhere on the board
/C7+: R8.1; also elsewhere on the board
/C8+: R9.1; also elsewhere on the board
/C9+: R10.1; also elsewhere on the board
/C10+: R11.1; also elsewhere on the board
/C11+: R12.1; also elsewhere on the board
/C12+: R13.1; also elsewhere on the board
/C13+: R14.1; also elsewhere on the board
/C14+: R15.1; also elsewhere on the board
/C15+: R16.1; also elsewhere on the board
/C16+: D2.2 (A), D5.2 (A), R17.1; also elsewhere on the board
/FUSE: R25.2, TP14.1; also elsewhere on the board
/I2C_SCL: U4.26 (SCL); also elsewhere on the board
/I2C_SDA: U4.27 (SDA); also elsewhere on the board
/PACK+: R29.2, R30.2; also elsewhere on the board
/REG18: C20.1, U4.24 (REG18); also elsewhere on the board
/TEMP1: C32.1, U4.21 (TS1); also elsewhere on the board
/TEMP2: C33.1, U4.23 (TS3); also elsewhere on the board
/TEMP_FETS: C35.1, U4.31 (DCHG); also elsewhere on the board
GND: C20.2, C25.2, C26.2, C29.2, C31.1, C32.2, C33.2, C35.2, C38.2, D10.2 (A), D11.2 (A), Q1.3 (S), R53.1, R65.2, U4.17 (VSS), U4.33 (RST_SHUT), U4.36 (REGIN), U4.37 (BREG); also elsewhere on the board
unnamed: D5.1 (K), R18.2
unnamed: Q1.2 (D), Q1.4 (D), R25.1
unnamed: Q1.1 (G), U4.38 (FUSE)
unnamed: R65.1, U4.34 (REG2), U4.35 (REG1)

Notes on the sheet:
TEMP inputs use internal 18k pull-up
CP capacity estimation: n_MOSFETs * C_iss * 10 For 4x IPT015N10N5 with 16nF: Choose 1µF > 640nF
bq76952 BMS ASIC
Wake signal is pulled up to approx 5V during SHUTDOWN. Voltage divider limits signal below 3.3V for MCU. WAKE pin is floating under normal operation. So we need external 3.3V supply for button state detection.
On/off push button
Trigger for fuse(s) on external PCB close to positive terminal, e.g. - Littelfuse ITV9550L5045 - Schott D6SE14-45
Balancing resistors >20R recommended. Resulting current: <100mA
Test points to short unused cell channels
Internal power supply if BAT+ cable is not (yet) connected.
Diodes to ensure VC0 stays close to GND

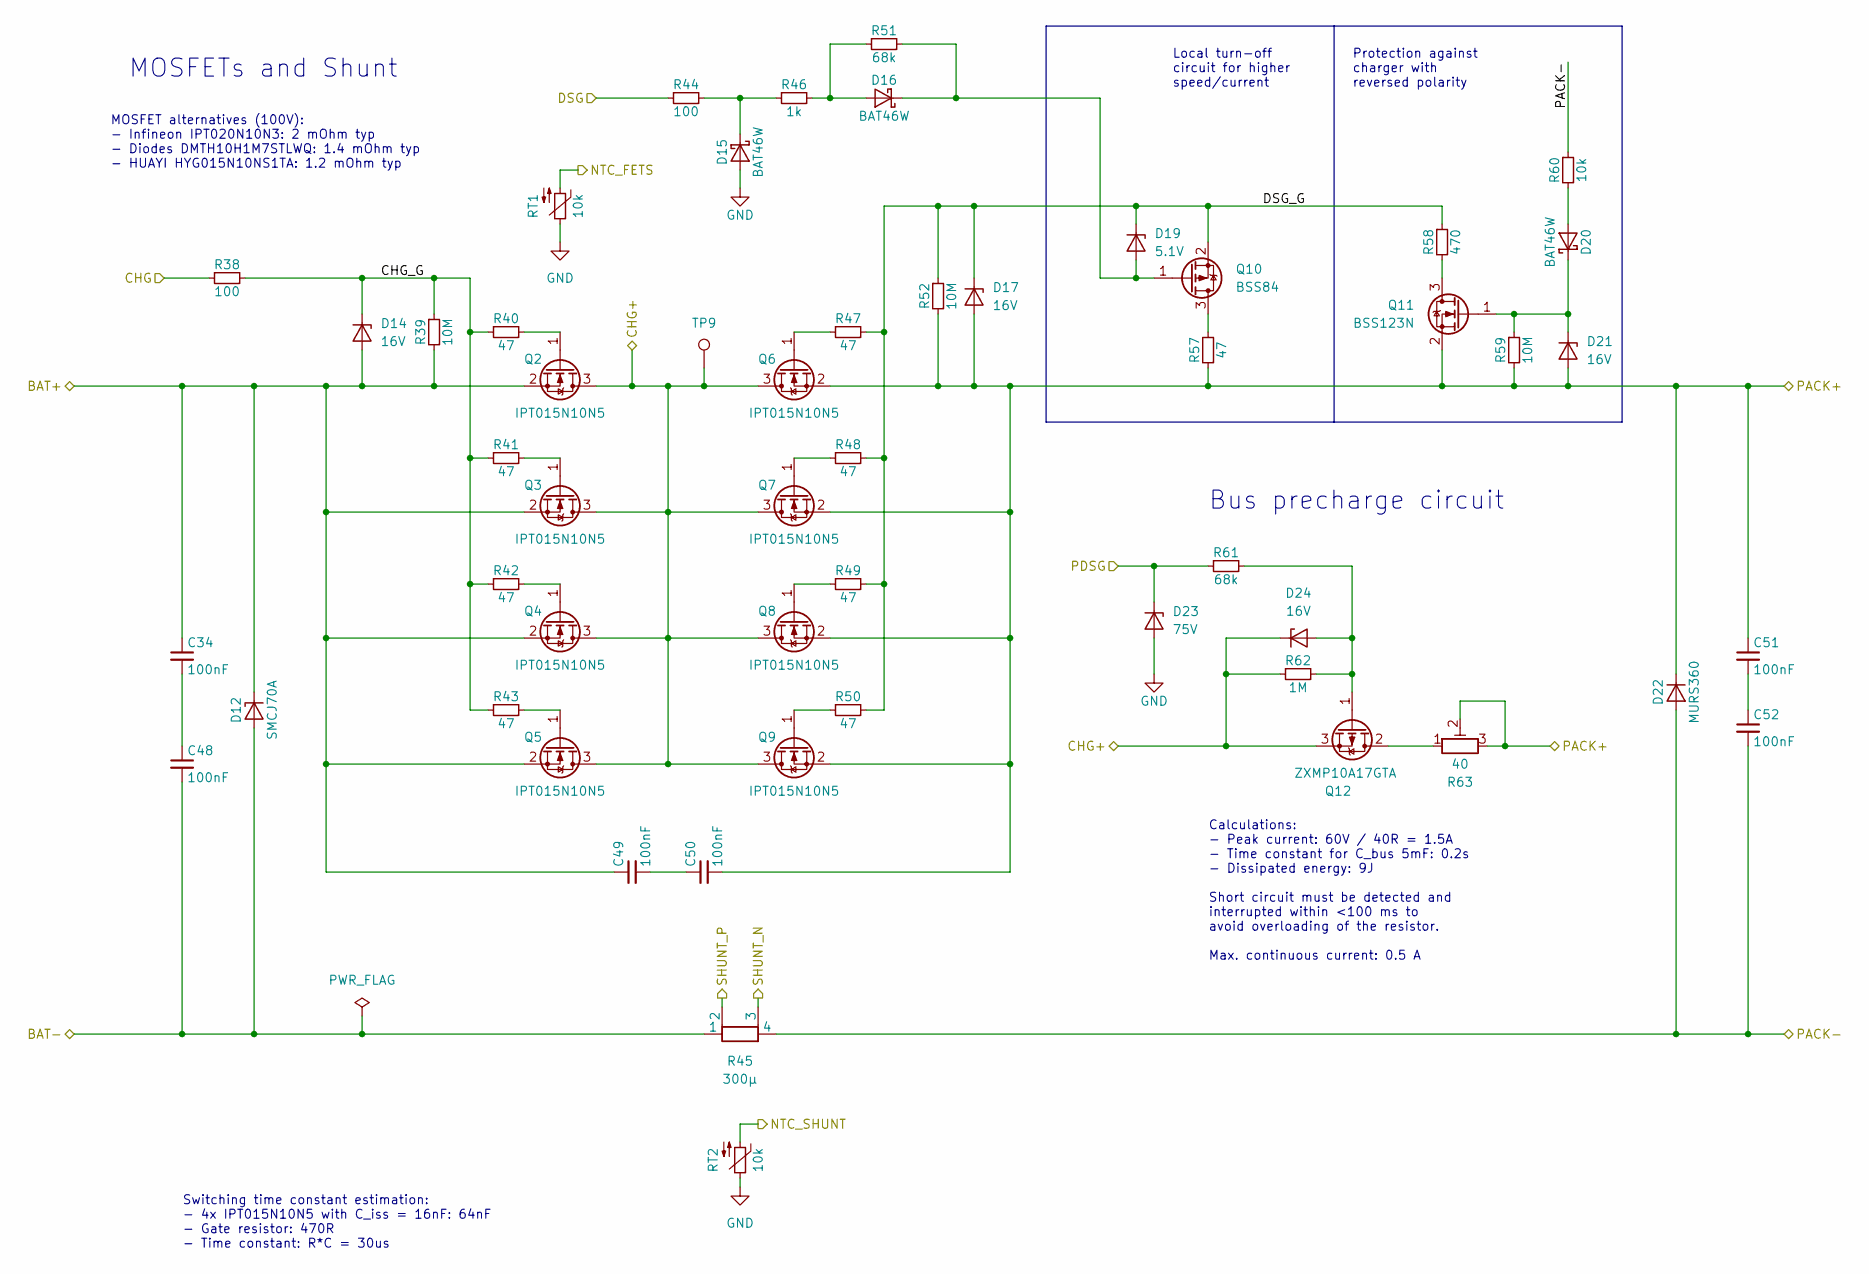
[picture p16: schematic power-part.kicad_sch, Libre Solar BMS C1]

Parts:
C34, C48, C49, C50, C51, C52: 100nF; C_0603_1608
D12: SMCJ70A; D_SMC; PartNumber SMCJ70A
D14, D17, D21, D24: 16V; D_SOD-123; PartNumber MMSZ5246B-7-F
D15, D16, D20: BAT46W; D_SOD-123; PartNumber BAT46W-7-F
D19: 5.1V; D_SOD-323; PartNumber BZT52C5V1S-7-F
D22: MURS360; D_SMC; PartNumber MURS360
D23: 75V; D_SOD-123; PartNumber MMSZ5267BT1G
Q2, Q3, Q4, Q5, Q6, Q7, Q8, Q9: IPT015N10N5; Infineon_PG-HSOF-8-1_ThermalVias; PartNumber IPT015N10N5
Q10: BSS84; SOT-23; PartNumber BSS84AK,215
Q11: BSS123N; SOT-23; PartNumber BSS123N
Q12: ZXMP10A17GTA; SOT-223-3_TabPin2; PartNumber ZXMP10A17GTA
R38, R44: 100; R_0603_1608
R39, R52, R59: 10M; R_0603_1608
R40, R41, R42, R43, R47, R48, R49, R50, R57: 47; R_0603_1608
R45: 300µ; R_Shunt_5931_Kelvin; PartNumber WSLP5931L3000FEA
R46: 1k; R_0603_1608
R51, R61: 68k; R_0603_1608
R58: 470; R_0603_1608
R60: 10k; R_0603_1608
R62: 1M; R_0603_1608
R63: 40; Bourns_PWR163; PartNumber PWR163S-25-40R0FE
RT1, RT2: 10k; R_0603_1608; PartNumber NTCG163JF103FT1S
TP9: TestPoint; TestPoint_Pad_D1.5mm

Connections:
/BAT+: C34.1, C49.1, D12.1 (K), D14.2 (A), Q2.2 (S), Q3.2 (S), Q4.2 (S), Q5.2 (S), R39.2; also elsewhere on the board
/BAT-: C48.2, D12.2 (A), R45.1; also elsewhere on the board
/BQ76952/CHG: R38.1; also elsewhere on the board
/BQ76952/DSG: R44.1; also elsewhere on the board
/BQ76952/PDSG: D23.1 (K), R61.1; also elsewhere on the board
/BQ76952/SHUNT_N: R45.3; also elsewhere on the board
/BQ76952/SHUNT_P: R45.2; also elsewhere on the board
/BQ76952/TEMP_SHUNT: RT2.2; also elsewhere on the board
/CHG+: D24.1 (K), Q2.3 (D), Q3.3 (D), Q4.3 (D), Q5.3 (D), Q6.3 (D), Q7.3 (D), Q8.3 (D), Q9.3 (D), Q12.3 (S), R62.1, TP9.1; also elsewhere on the board
/PACK+: C50.2, C51.1, D17.2 (A), D21.2 (A), D22.1 (K), Q6.2 (S), Q7.2 (S), Q8.2 (S), Q9.2 (S), Q11.2 (S), R52.2, R57.1, R59.2, R63.2, R63.3; also elsewhere on the board
/PACK-: C52.2, D22.2 (A), R45.4, R60.1; also elsewhere on the board
/Power Part/CHG_G: D14.1 (K), R38.2, R39.1, R40.1, R41.1, R42.1, R43.1
/Power Part/DSG_G: D17.1 (K), D19.1 (K), Q10.2 (S), R47.2, R48.2, R49.2, R50.2, R52.1, R58.1
/TEMP_FETS: RT1.2; also elsewhere on the board
GND: D15.2 (A), D23.2 (A), RT1.1, RT2.1; also elsewhere on the board
unnamed: C34.2, C48.1
unnamed: C49.2, C50.1
unnamed: C51.2, C52.1
unnamed: D15.1 (K), R44.2, R46.1
unnamed: D16.2 (A), R46.2, R51.1
unnamed: D16.1 (K), D19.2 (A), Q10.1 (G), R51.2
unnamed: D20.2 (A), R60.2
unnamed: D20.1 (K), D21.1 (K), Q11.1 (G), R59.1
unnamed: D24.2 (A), Q12.1 (G), R61.2, R62.2
unnamed: Q2.1 (G), R40.2
unnamed: Q3.1 (G), R41.2
unnamed: Q4.1 (G), R42.2
unnamed: Q5.1 (G), R43.2
unnamed: Q6.1 (G), R47.1
unnamed: Q7.1 (G), R48.1
unnamed: Q8.1 (G), R49.1
unnamed: Q9.1 (G), R50.1
unnamed: Q10.3 (D), R57.2
unnamed: Q11.3 (D), R58.2
unnamed: Q12.2 (D), R63.1

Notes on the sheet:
Protection against charger with reversed polarity
Switching time constant estimation: - 4x IPT015N10N5 with C_iss = 16nF: 64nF - Gate resistor: 470R - Time constant: R*C = 30us
MOSFET alternatives (100V): - Infineon IPT020N10N3: 2 mOhm typ - Diodes DMTH10H1M7STLWQ: 1.4 mOhm typ - HUAYI HYG015N10NS1TA: 1.2 mOhm typ
MOSFETs and Shunt
Local turn-off circuit for higher speed/current
Bus precharge circuit
Calculations: - Peak current: 60V / 40R = 1.5A - Time constant for C_bus 5mF: 0.2s - Dissipated energy: 9J Short circuit must be detected and interrupted within <100 ms to avoid overloading of the resistor. Max. continuous current: 0.5 A

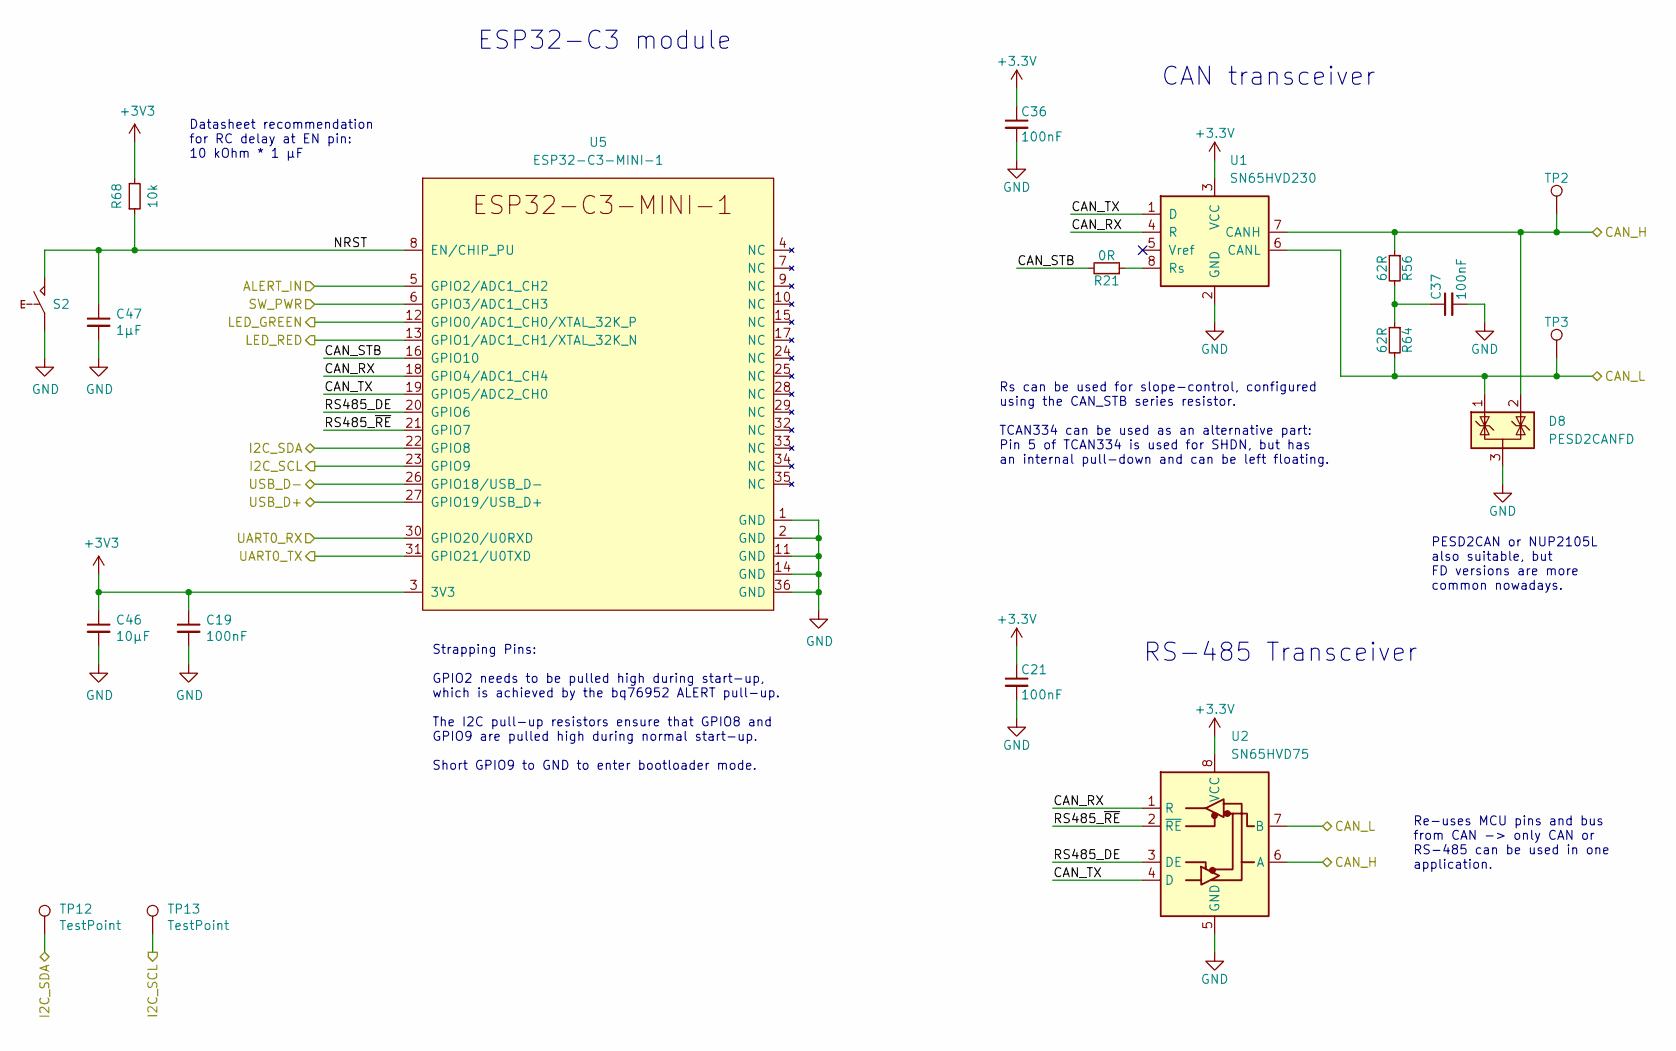
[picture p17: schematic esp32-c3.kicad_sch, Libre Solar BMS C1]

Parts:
C19, C21, C36, C37: 100nF; C_0603_1608
C46: 10µF; C_0805_2012; PartNumber GRM21BR61E106KA73L
C47: 1µF; C_0603_1608
D8: PESD2CANFD; SOT-23; PartNumber PESD2CANFD24V-TR
R21: 0R; R_0603_1608
R56, R64: 62R; R_0603_1608
R68: 10k; R_0603_1608
S2: SW_PUSH; SW_SPST_TL3305A; PartNumber TL3305AF160QG
TP2, TP3, TP12, TP13: TestPoint; TestPoint_Pad_D1.5mm
U1: SN65HVD230; SOIC-8_3.9x4.9mm_P1.27mm; PartNumber SN65HVD230D
U2: SN65HVD75; SOIC-8_3.9x4.9mm_P1.27mm; PartNumber SN65HVD75DR
U5: ESP32-C3-MINI-1; PartNumber ESP32-C3-MINI-1-N4

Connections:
/BQ76952/ALERT: U5.5 (GPIO2/ADC1_CH2); also elsewhere on the board
/BTN_LOW: U5.6 (GPIO3/ADC1_CH3); also elsewhere on the board
/CAN_H: D8.2 (K), R56.1, TP2.1, U1.7 (CANH), U2.6 (A); also elsewhere on the board
/CAN_L: D8.1 (K), R64.2, TP3.1, U1.6 (CANL), U2.7 (B); also elsewhere on the board
/ESP32-C3 MCU/CAN_RX: U1.4 (R), U2.1 (R), U5.18 (GPIO4/ADC1_CH4)
/ESP32-C3 MCU/CAN_STB: R21.2, U5.16 (GPIO10)
/ESP32-C3 MCU/CAN_TX: U1.1 (D), U2.4 (D), U5.19 (GPIO5/ADC2_CH0)
/ESP32-C3 MCU/NRST: C47.1, R68.1, S2.2, U5.8 (EN/CHIP_PU)
/ESP32-C3 MCU/RS485_DE: U2.3 (DE), U5.20 (GPIO6)
/ESP32-C3 MCU/RS485_~RE: U2.2 (~RE), U5.21 (GPIO7)
/ESP32-C3 MCU/USB_D+: U5.27 (GPIO19/USB_D+); also elsewhere on the board
/ESP32-C3 MCU/USB_D-: U5.26 (GPIO18/USB_D-); also elsewhere on the board
/I2C_SCL: TP13.1, U5.23 (GPIO9); also elsewhere on the board
/I2C_SDA: TP12.1, U5.22 (GPIO8); also elsewhere on the board
/LED_GREEN: U5.12 (GPIO0/ADC1_CH0/XTAL_32K_P); also elsewhere on the board
/LED_RED: U5.13 (GPIO1/ADC1_CH1/XTAL_32K_N); also elsewhere on the board
/UART_RX: U5.30 (GPIO20/U0RXD); also elsewhere on the board
/UART_TX: U5.31 (GPIO21/U0TXD); also elsewhere on the board
GND: C19.2, C21.2, C36.2, C37.2, C46.2, C47.2, D8.3 (A), S2.1, U1.2 (GND), U2.5 (GND), U5.1 (GND), U5.2 (GND), U5.11 (GND), U5.14 (GND), U5.36 (GND); also elsewhere on the board
unnamed: C37.1, R56.2, R64.1
unnamed: R21.1, U1.8 (Rs)

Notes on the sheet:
Datasheet recommendation for RC delay at EN pin: 10 kOhm * 1 µF
Strapping Pins: GPIO2 needs to be pulled high during start-up, which is achieved by the bq76952 ALERT pull-up. The I2C pull-up resistors ensure that GPIO8 and GPIO9 are pulled high during normal start-up. Short GPIO9 to GND to enter bootloader mode.
RS-485 Transceiver
Re-uses MCU pins and bus from CAN -> only CAN or RS-485 can be used in one application.
PESD2CAN or NUP2105L also suitable, but FD versions are more common nowadays.
CAN transceiver
ESP32-C3 module
Rs can be used for slope-control, configured using the CAN_STB series resistor. TCAN334 can be used as an alternative part: Pin 5 of TCAN334 is used for SHDN, but has an internal pull-down and can be left floating.

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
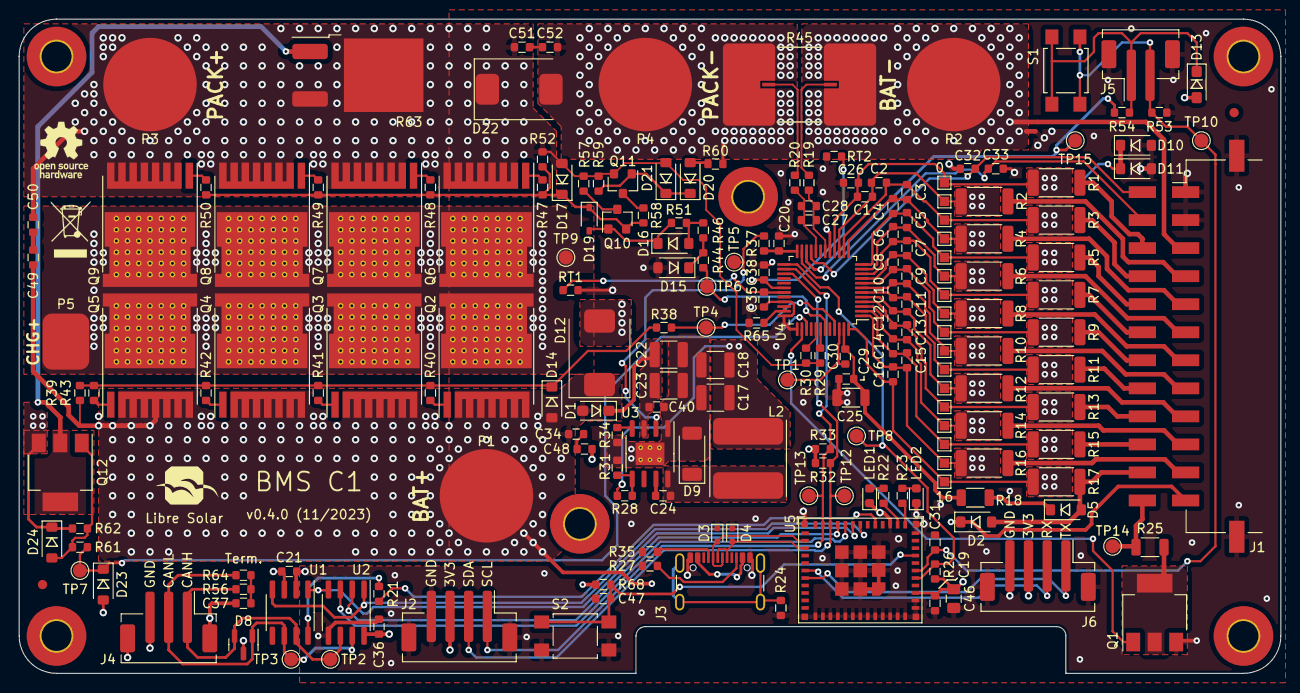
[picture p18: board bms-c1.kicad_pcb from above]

Board: 4 copper layers, 135.0 x 70.0 mm, 208 parts (0 on the bottom side), 117 nets.

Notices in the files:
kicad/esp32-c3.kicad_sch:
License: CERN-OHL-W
